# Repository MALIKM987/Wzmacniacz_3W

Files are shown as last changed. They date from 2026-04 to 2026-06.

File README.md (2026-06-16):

# Wzmacniacz audio 3 W z wejściem S/PDIF i DAC







## Spis treści

1. [Opis projektu](#opis-projektu)
2. [Najważniejsze parametry](#najważniejsze-parametry)
3. [Architektura systemu](#architektura-systemu)
4. [Główne bloki funkcjonalne](#główne-bloki-funkcjonalne)
5. [Wyniki symulacji](#wyniki-symulacji)
6. [PCB i pliki projektowe](#pcb-i-pliki-projektowe)
7. [Struktura dokumentacji](#struktura-dokumentacji)
8. [Co pokazuje ten projekt](#co-pokazuje-ten-projekt)
9. [Status projektu](#status-projektu)

## Opis projektu

Repozytorium dokumentuje projekt **wzmacniacza audio z wejściem cyfrowym S/PDIF, przetwornikiem DAC AD1955 oraz tranzystorową końcówką mocy**. Projekt obejmuje tor cyfrowy, tor analogowy, stopień mocy, zasilanie, symulacje LTspice oraz projekt PCB wykonany w Altium Designer.

Założeniem było stworzenie układu, który odbiera sygnał cyfrowy audio przez wejście koaksjalne S/PDIF, konwertuje go do formatu I2S, przetwarza w DAC na sygnał analogowy, a następnie wzmacnia w tranzystorowej końcówce mocy.

Projekt jest dobrym przykładem połączenia elektroniki analogowej, cyfrowej, audio, symulacji oraz projektowania PCB.

## Najważniejsze parametry

| Parametr | Wartość / założenie |
|---|---|
| Typ urządzenia | wzmacniacz audio z wejściem cyfrowym |
| Wejście audio | koaksjalne S/PDIF |
| Konwersja S/PDIF -> I2S | DIR9001 |
| DAC | AD1955 |
| Konwersja I/V | wzmacniacze operacyjne AD797 |
| Sterowanie | mikrokontroler STM32F103, SPI |
| Stopień mocy | tranzystorowy, klasa A, topologia inspirowana Linsley-Hood 1969 |
| Tranzystory mocy | MJL4281AG |
| Tranzystory driverów | BD139 |
| Tranzystory pomocnicze | BC557C |
| Założona moc wyjściowa | powyżej 3 W |
| Wynik symulacji mocy | ok. 12,9 W RMS dla obciążenia 8 ohm |
| Pasmo z symulacji | ok. 11,14 Hz - 5,18 MHz |
| Wzmocnienie napięciowe | ok. 16,25 V/V, czyli 24,22 dB przy 1 kHz |
| THD z symulacji | ok. 4,22E-03 |
| Sprawność z symulacji | ok. 25,32% |
| Zasilanie stopnia mocy | +36 V |
| Zasilanie analogowe | symetryczne +/-12 V |
| Zasilanie pomocnicze | +/-5 V oraz +3,3 V |
| Projekt PCB | Altium Designer |
| Symulacje | LTspice |

## Architektura systemu

```mermaid
flowchart LR
    A[Wejscie S/PDIF RCA] --> B[DIR9001 konwerter S/PDIF do I2S]
    B --> C[Bufor SN74LVU04A]
    C --> D[DAC AD1955]
    D --> E[Konwersja I/V i filtracja AD797]
    E --> F[Tranzystorowy wzmacniacz mocy klasa A]
    F --> G[Wyjscie glosnikowe]

    H[STM32F103] -->|SPI| D
    H -->|mute / volume| D

    I[Zasilanie] --> B
    I --> D
    I --> E
    I --> F
    I --> H
```

## Główne bloki funkcjonalne

| Blok | Opis | Dokumentacja |
|---|---|---|
| Konwerter S/PDIF -> I2S | odbiór cyfrowego sygnału audio i konwersja do I2S | [docs/03_tor_cyfrowy_spdif_i2s.md](docs/03_tor_cyfrowy_spdif_i2s.md) |
| DAC i tor analogowy | AD1955, konwersja I/V, filtracja i buforowanie | [docs/04_dac_tor_analogowy.md](docs/04_dac_tor_analogowy.md) |
| Mikrokontroler | sterowanie DAC przez SPI, mute, regulacja głośności | [docs/07_mcu_sterowanie.md](docs/07_mcu_sterowanie.md) |
| Wzmacniacz mocy | tranzystorowa końcówka mocy w klasie A | [docs/05_wzmacniacz_mocy.md](docs/05_wzmacniacz_mocy.md) |
| Zasilanie | +36 V, +/-12 V, +/-5 V, +3,3 V | [docs/06_zasilanie.md](docs/06_zasilanie.md) |
| PCB | projekt w Altium, rozmieszczenie bloków, Gerbery | [docs/09_pcb_altium.md](docs/09_pcb_altium.md) |
| Symulacje | LTspice, pasmo, wzmocnienie, moc, THD, sprawność | [docs/08_symulacje_ltspice.md](docs/08_symulacje_ltspice.md) |

## Wyniki symulacji

| Badanie | Wynik |
|---|---|
| Pasmo przenoszenia | ok. 11,14 Hz - 5,18 MHz |
| Wzmocnienie napięciowe | ok. 16,25 V/V |
| Wzmocnienie w dB | ok. 24,22 dB |
| Moc RMS | ok. 12,9 W |
| THD | ok. 4,22E-03 |
| Sprawność | ok. 25,32% |

Szczegóły znajdują się w pliku [docs/08_symulacje_ltspice.md](docs/08_symulacje_ltspice.md).

## PCB i pliki projektowe

Projekt PCB wykonano w **Altium Designer**. W repozytorium znajdują się pliki projektu, pliki wyjściowe oraz Gerbery.

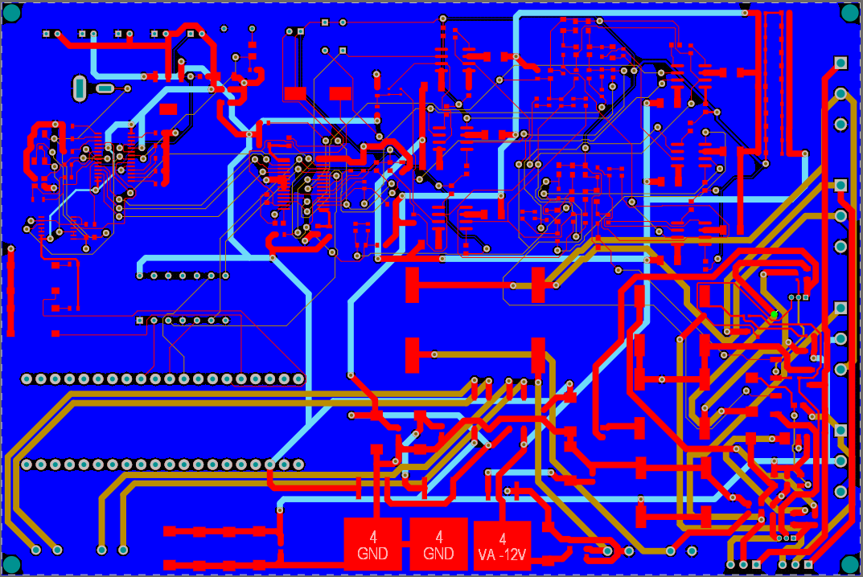
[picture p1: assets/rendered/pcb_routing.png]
Podgląd PCB ze sprawozdania


Najważniejsze katalogi źródłowe:

| Katalog | Zawartość |
|---|---|
| `pcb/` | projekt PCB Altium Designer |
| `pcb/Gerber/` | pliki produkcyjne Gerber |
| `sym/` | symulacje LTspice |
| `sprawozdanie/` | sprawozdanie projektowe |
| `prezentacja/` | prezentacja projektu |
| `literatura/` | noty katalogowe komponentów |

## Struktura dokumentacji

| Plik | Zawartość |
|---|---|
| [docs/00_spis_tresci.md](docs/00_spis_tresci.md) | pełny spis dokumentacji |
| [docs/01_architektura.md](docs/01_architektura.md) | architektura systemu |
| [docs/02_parametry_projektu.md](docs/02_parametry_projektu.md) | parametry i założenia |
| [docs/03_tor_cyfrowy_spdif_i2s.md](docs/03_tor_cyfrowy_spdif_i2s.md) | DIR9001, S/PDIF, I2S |
| [docs/04_dac_tor_analogowy.md](docs/04_dac_tor_analogowy.md) | AD1955 i tor analogowy |
| [docs/05_wzmacniacz_mocy.md](docs/05_wzmacniacz_mocy.md) | końcówka mocy klasy A |
| [docs/06_zasilanie.md](docs/06_zasilanie.md) | moduł zasilania |
| [docs/07_mcu_sterowanie.md](docs/07_mcu_sterowanie.md) | sterowanie mikrokontrolerem |
| [docs/08_symulacje_ltspice.md](docs/08_symulacje_ltspice.md) | wyniki symulacji |
| [docs/09_pcb_altium.md](docs/09_pcb_altium.md) | projekt PCB |
| [docs/10_bom_komponenty.md](docs/10_bom_komponenty.md) | elementy i ich rola |
| [docs/11_testy_walidacja.md](docs/11_testy_walidacja.md) | testy i walidacja |
| [docs/12_portfolio.md](docs/12_portfolio.md) | opis projektu do CV |
| [docs/13_todo_przed_publikacja.md](docs/13_todo_przed_publikacja.md) | lista poprawek przed publikacją |

## Co pokazuje ten projekt

Projekt pokazuje praktyczne umiejętności z zakresu:

- projektowania torów audio,
- doboru elementów analogowych i cyfrowych,
- projektowania wzmacniaczy tranzystorowych,
- pracy z układami DAC i interfejsem I2S,
- sterowania układami audio przez SPI,
- symulacji w LTspice,
- projektowania PCB w Altium Designer,
- przygotowania dokumentacji technicznej,
- analizy wyników: pasmo, wzmocnienie, moc, THD i sprawność.

## Status projektu

Projekt zawiera dokumentację, symulacje LTspice, schematy, PCB i Gerbery. Przed traktowaniem go jako gotowy produkt sprzętowy należy jeszcze wykonać weryfikację prototypu, pomiary laboratoryjne, kontrolę termiczną końcówki mocy oraz końcową walidację PCB.

## Autor

**Maciej Molik**

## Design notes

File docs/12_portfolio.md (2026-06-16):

# Opis projektu do portfolio

## Krótki opis

Wzmacniacz audio z wejściem S/PDIF, konwersją do I2S, przetwornikiem DAC AD1955 oraz tranzystorową końcówką mocy klasy A. Projekt obejmuje dobór komponentów, symulacje LTspice, projekt PCB w Altium Designer, dokumentację techniczną i analizę parametrów.

## Opis do CV

Zaprojektowano wzmacniacz audio z cyfrowym wejściem S/PDIF, konwersją DIR9001 do I2S, przetwornikiem AD1955 oraz tranzystorową końcówką mocy opartą o MJL4281AG, BD139 i BC557C. Wykonano symulacje LTspice, projekt PCB w Altium Designer oraz dokumentację techniczną obejmującą tor cyfrowy, analogowy, zasilanie i końcówkę mocy.

## Umiejętności pokazane w projekcie

- projektowanie torów audio,
- dobór komponentów analogowych i cyfrowych,
- projektowanie końcówki mocy,
- praca z DAC i interfejsem I2S,
- sterowanie układami przez SPI,
- symulacje LTspice,
- projektowanie PCB w Altium Designer,
- analiza parametrów: pasmo, wzmocnienie, moc, THD, sprawność,
- przygotowanie dokumentacji inżynierskiej.

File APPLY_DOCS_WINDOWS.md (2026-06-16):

# Jak zastosować tę paczkę w repozytorium

## 1. Rozpakuj ZIP

Rozpakuj paczkę dokumentacji obok lokalnego repozytorium projektu.

## 2. Wejdź do repozytorium

```powershell
cd "SCIEZKA_DO_REPO"
```

## 3. Utwórz branch

```powershell
git checkout main
git pull
git checkout -b docs/full-polish-audio-amplifier-docs
```

## 4. Skopiuj pliki

Jeżeli paczka jest rozpakowana obok repozytorium:

```powershell
robocopy "..\wzmacniacz_3w_full_polish_docs" "." /E
```

Kod wyjścia `1` z `robocopy` zwykle oznacza, że pliki zostały poprawnie skopiowane.

## 5. Commit i push

```powershell
git status
git add README.md docs assets CHANGELOG.md .gitignore
git commit -m "Add full Polish amplifier documentation"
git push -u origin docs/full-polish-audio-amplifier-docs
```

## 6. Otwórz Pull Request

Na GitHubie otwórz PR do `main`.

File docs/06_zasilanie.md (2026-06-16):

# Moduł zasilania

## Cel modułu

Moduł zasilania dostarcza stabilne napięcia dla części cyfrowej, analogowej oraz końcówki mocy. W projekcie występuje kilka domen zasilania, ponieważ różne bloki wymagają różnych napięć i poziomów zakłóceń.

## Napięcia w projekcie

| Napięcie | Zastosowanie |
|---|---|
| +36 V | końcówka mocy |
| +/-12 V | wzmacniacze operacyjne w torze analogowym |
| +5 V | część cyfrowa i pomocnicza |
| -5 V | wybrane obwody analogowe |
| +3,3 V | układy cyfrowe wymagające niższego napięcia |

## Elementy modułu

| Element | Rola |
|---|---|
| MB6S | mostki prostownicze |
| Kondensatory elektrolityczne | filtracja napięcia po prostowaniu |
| L7805 | stabilizacja +5 V |
| L7905 | stabilizacja -5 V |
| REG1117-3.3 | stabilizacja +3,3 V |
| Dławiki ferrytowe | ograniczenie zakłóceń i separacja domen |

## Diagram zasilania

```mermaid
flowchart LR
    A[Wejscie zasilania] --> B[Prostowniki]
    B --> C[Filtracja kondensatorami]
    C --> D[+36 V koncowka mocy]
    C --> E[+/-12 V tor analogowy]
    C --> F[+/-5 V]
    F --> G[+3.3 V]
    G --> H[DIR9001 / logika / MCU]
```

## Uwagi projektowe

W torze audio zasilanie ma bezpośredni wpływ na szumy i stabilność pracy. Należy dbać o krótkie ścieżki prądowe, separację masy analogowej i cyfrowej oraz odpowiednią filtrację przy każdym układzie scalonym.

## Schemat ze sprawozdania

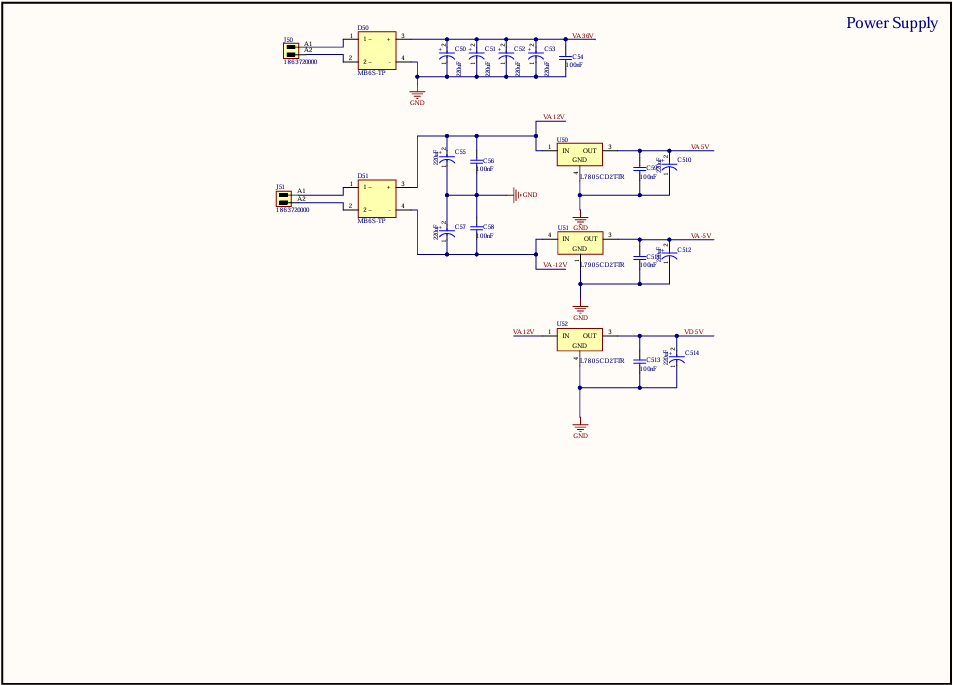
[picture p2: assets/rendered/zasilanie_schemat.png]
Schemat zasilania


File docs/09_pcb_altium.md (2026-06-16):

# Projekt PCB w Altium Designer

## Cel projektu PCB

Celem PCB było połączenie części cyfrowej, analogowej, zasilania i końcówki mocy w jednym projekcie. Płytka musi uwzględniać zarówno sygnały cyfrowe o wysokich zboczach, jak i niskoszumowy tor analogowy.

## Pliki projektowe

| Plik / katalog | Opis |
|---|---|
| `pcb/PCB_Project.PrjPcb` | projekt Altium |
| `pcb/Wzmacniacz audio.SchDoc` | schemat ideowy |
| `pcb/PCB_wzmacniacz_audio.PcbDoc` | projekt płytki |
| `pcb/Gerber/` | pliki produkcyjne |
| `pcb/Project Outputs for PCB_Project/` | wygenerowane pliki wyjściowe |
| `pcb/PCB_Project.pdf` | eksport projektu do PDF |

## Założenia PCB

- oddzielenie sekcji cyfrowej i analogowej,
- krótkie ścieżki dla sygnałów I2S,
- odpowiednio szerokie ścieżki zasilania i stopnia mocy,
- sensowne rozmieszczenie złączy,
- miejsce na elementy większej mocy i potencjalne radiatory,
- ograniczenie pętli masy,
- filtracja przy układach scalonych.

## Podgląd projektu

### Widok 3D PCB ze sprawozdania

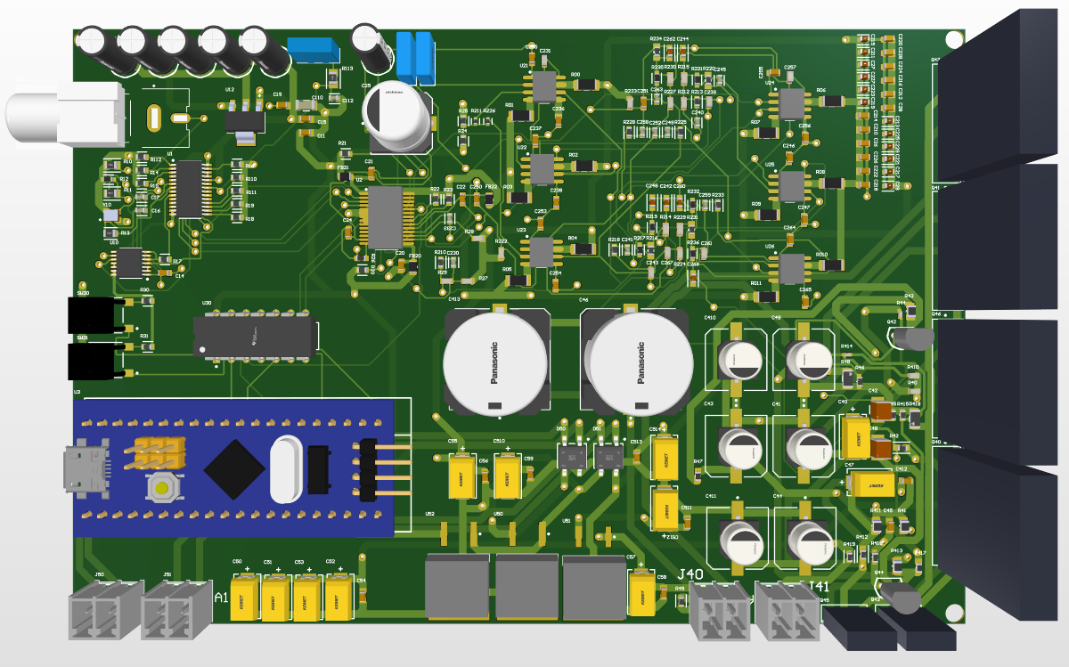
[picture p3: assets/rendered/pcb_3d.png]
Widok 3D PCB


### Routing PCB ze sprawozdania

PCB routing

### Szczegółowy widok PCB ze sprawozdania

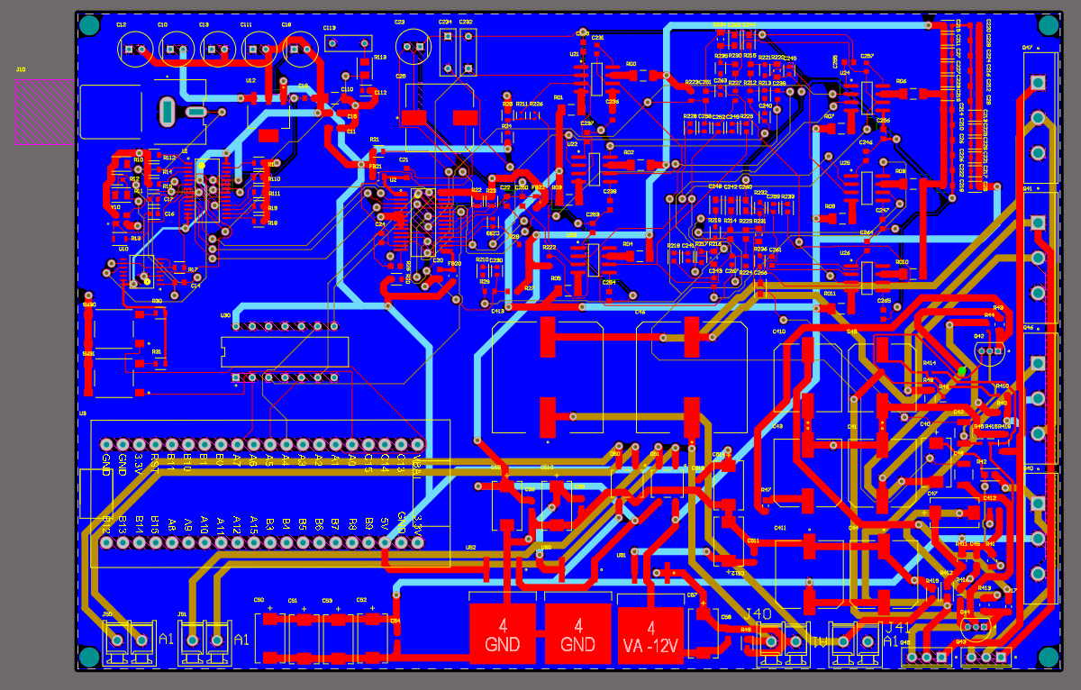
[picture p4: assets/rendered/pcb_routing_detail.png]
PCB routing detail


## Rzeczy do sprawdzenia przed produkcją

- DRC w Altium,
- szerokości ścieżek prądowych,
- odstępy izolacyjne,
- termika tranzystorów mocy,
- prowadzenie mas analogowych i cyfrowych,
- poprawność footprintów,
- polaryzacje kondensatorów i diod,
- zgodność Gerberów z projektem.

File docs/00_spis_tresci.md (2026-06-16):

# Spis treści dokumentacji

## Dokumenty główne

1. [Architektura systemu](01_architektura.md)
2. [Parametry projektu](02_parametry_projektu.md)
3. [Tor cyfrowy S/PDIF -> I2S](03_tor_cyfrowy_spdif_i2s.md)
4. [DAC i tor analogowy](04_dac_tor_analogowy.md)
5. [Wzmacniacz mocy](05_wzmacniacz_mocy.md)
6. [Zasilanie](06_zasilanie.md)
7. [Mikrokontroler i sterowanie](07_mcu_sterowanie.md)
8. [Symulacje LTspice](08_symulacje_ltspice.md)
9. [PCB w Altium Designer](09_pcb_altium.md)
10. [BOM i komponenty](10_bom_komponenty.md)
11. [Testy i walidacja](11_testy_walidacja.md)
12. [Opis do portfolio](12_portfolio.md)
13. [TODO przed publikacją](13_todo_przed_publikacja.md)

## Najważniejsze pliki źródłowe projektu

| Ścieżka | Znaczenie |
|---|---|
| `pcb/PCB_Project.PrjPcb` | projekt Altium Designer |
| `pcb/Wzmacniacz audio.SchDoc` | schemat ideowy |
| `pcb/PCB_wzmacniacz_audio.PcbDoc` | projekt PCB |
| `pcb/Gerber/` | pliki produkcyjne |
| `sym/amplifier.asc` | symulacja wzmacniacza mocy w LTspice |
| `sym/Power supply.asc` | symulacja zasilania w LTspice |
| `sprawozdanie/Sprawozdanie.pdf` | pełne sprawozdanie |
| `prezentacja/Prezentacja_WM.pdf` | prezentacja projektu |
| `literatura/` | noty katalogowe elementów |

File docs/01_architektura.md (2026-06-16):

# Architektura systemu

## Cel architektury

Projekt składa się z kilku bloków funkcjonalnych połączonych w jeden tor audio. Sygnał wejściowy jest cyfrowy, a sygnał wyjściowy jest analogowy i zasila głośnik.

## Diagram wysokiego poziomu

```mermaid
flowchart LR
    A[Wejscie koaksjalne S/PDIF] --> B[DIR9001]
    B --> C[I2S: LRCK, BCK, DATA]
    C --> D[SN74LVU04A]
    D --> E[AD1955 DAC]
    E --> F[Konwersja I/V AD797]
    F --> G[Filtracja analogowa]
    G --> H[Wzmacniacz mocy klasa A]
    H --> I[Glosnik]

    J[STM32F103] -->|SPI| E
    J -->|Mute i regulacja| E

    K[Zasilanie] --> B
    K --> E
    K --> F
    K --> H
    K --> J
```

## Przepływ sygnału audio

1. Sygnał cyfrowy S/PDIF trafia do gniazda RCA.
2. DIR9001 dekoduje S/PDIF i odzyskuje sygnały zegarowe oraz dane audio.
3. Sygnały I2S są buforowane i kształtowane przez SN74LVU04A.
4. AD1955 zamienia dane cyfrowe PCM na sygnał analogowy prądowy.
5. Wzmacniacze operacyjne AD797 realizują konwersję prąd-napięcie oraz filtrację.
6. Tranzystorowy stopień mocy wzmacnia sygnał do poziomu odpowiedniego dla głośnika.
7. Moduł zasilania dostarcza oddzielne napięcia dla części cyfrowej, analogowej i mocy.

## Podział na domeny

| Domena | Bloki |
|---|---|
| Cyfrowa | S/PDIF, DIR9001, SN74LVU04A, STM32F103, SPI |
| Konwersja C/A | AD1955 |
| Analogowa niskosygnałowa | konwersja I/V, AD797, filtracja |
| Moc | końcówka tranzystorowa, MJL4281AG, BD139, BC557C |
| Zasilanie | prostowniki, stabilizatory, kondensatory, separacja mas |

## Dlaczego taki podział jest ważny

W projekcie audio trzeba ograniczać przenikanie zakłóceń z części cyfrowej do analogowej. Dlatego istotny jest podział funkcjonalny, oddzielenie ścieżek zasilania, odpowiednie prowadzenie mas oraz logiczne rozmieszczenie bloków na PCB.

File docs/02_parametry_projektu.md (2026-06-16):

# Parametry projektu

## Założenia projektowe

| Parametr | Wartość |
|---|---|
| Moc wyjściowa | powyżej 3 W |
| Wejście | koaksjalne S/PDIF |
| Konwersja S/PDIF do I2S | DIR9001 |
| Przetwornik C/A | AD1955 |
| Sterowanie | mikrokontroler STM32F103, SPI |
| Stopień mocy | tranzystorowy, klasa A |
| Topologia końcówki | inspirowana Linsley-Hood 1969 |
| Zasilanie końcówki mocy | +36 V |
| Zasilanie analogowe | +/-12 V |
| Zasilanie pomocnicze | +/-5 V, +3,3 V |
| Narzędzia projektowe | Altium Designer, LTspice |

## Wyniki z symulacji

| Badany parametr | Wynik |
|---|---|
| Pasmo przenoszenia | ok. 11,14 Hz - 5,18 MHz |
| Wzmocnienie napięciowe | ok. 16,25 V/V |
| Wzmocnienie w dB | ok. 24,22 dB przy 1 kHz |
| Moc RMS | ok. 12,9 W |
| THD | ok. 4,22E-03 |
| Sprawność | ok. 25,32% |
| Obciążenie symulacyjne | 8 ohm |

## Uwaga o interpretacji wyników

Wyniki symulacji pokazują potencjalne parametry układu, ale nie zastępują pomiarów rzeczywistego prototypu. W przypadku końcówki mocy klasy A szczególnie ważne są pomiary temperatury, stabilności punktu pracy oraz rzeczywistego THD.

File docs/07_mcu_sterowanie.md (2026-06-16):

# Mikrokontroler i sterowanie

## Cel modułu

Mikrokontroler odpowiada za konfigurację przetwornika AD1955 i funkcje użytkowe, takie jak regulacja głośności, mute oraz potencjalna obsługa przycisków lub LED.

## Zakładany mikrokontroler

W dokumentacji projektu pojawia się mikrokontroler **STM32F103**. Jego główną rolą jest sterowanie układem DAC przez SPI.

## Funkcje sterowania

| Funkcja | Opis |
|---|---|
| Konfiguracja DAC | ustawienie formatu danych i trybu pracy AD1955 |
| Regulacja głośności | zapis wartości do rejestrów głośności DAC |
| Mute | wyciszenie sygnału audio |
| De-emfaza | opcjonalna konfiguracja trybu DAC |
| Interfejs użytkownika | potencjalne przyciski, enkoder lub LED |

## Diagram sterowania

```mermaid
flowchart LR
    A[Przyciski / UI] --> B[STM32F103]
    B -->|SPI: CCLK| C[AD1955]
    B -->|SPI: CLATCH| C
    B -->|SPI: CDATA| C
    B -->|MUTE| C
```

## Możliwa sekwencja startowa

1. Inicjalizacja zasilania i zegarów.
2. Reset lub ustawienie stanu początkowego DAC.
3. Konfiguracja formatu wejściowego.
4. Ustawienie poziomu głośności.
5. Wyłączenie mute po stabilizacji toru audio.

## Możliwe rozszerzenia

- enkoder do regulacji głośności,
- diody LED statusu,
- wybór źródła sygnału,
- zapamiętywanie ustawień,
- interfejs użytkownika z wyświetlaczem.

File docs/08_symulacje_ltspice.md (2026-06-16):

# Symulacje LTspice

## Cel symulacji

Symulacje służą do weryfikacji działania wzmacniacza mocy i zasilania przed wykonaniem lub uruchomieniem prototypu. W projekcie znajdują się pliki LTspice:

| Plik | Znaczenie |
|---|---|
| `sym/amplifier.asc` | symulacja końcówki mocy |
| `sym/Power supply.asc` | symulacja zasilania |

## Wyniki

| Badanie | Wynik |
|---|---|
| Pasmo przenoszenia | ok. 11,14 Hz - 5,18 MHz |
| Wzmocnienie napięciowe | ok. 16,25 V/V |
| Wzmocnienie w dB | ok. 24,22 dB |
| Moc RMS | ok. 12,9 W |
| THD | ok. 4,22E-03 |
| Sprawność | ok. 25,32% |

## Wzory używane w analizie

Wzmocnienie napięciowe:

$$
A_v = \frac{V_{out}}{V_{in}}
$$

Wzmocnienie w dB:

$$
A_{v,dB} = 20 \log_{10}(A_v)
$$

Moc na obciążeniu:

$$
P_{RMS} = \frac{V_{RMS}^2}{R}
$$

THD:

$$
THD = \frac{\sqrt{U_2^2 + U_3^2 + U_4^2 + ...}}{U_1}
$$

Sprawność:

$$
\eta = \frac{P_{out,RMS}}{I_{spocz} \cdot V_{CC}}
$$

## Zrzuty z symulacji

### Pasmo przenoszenia

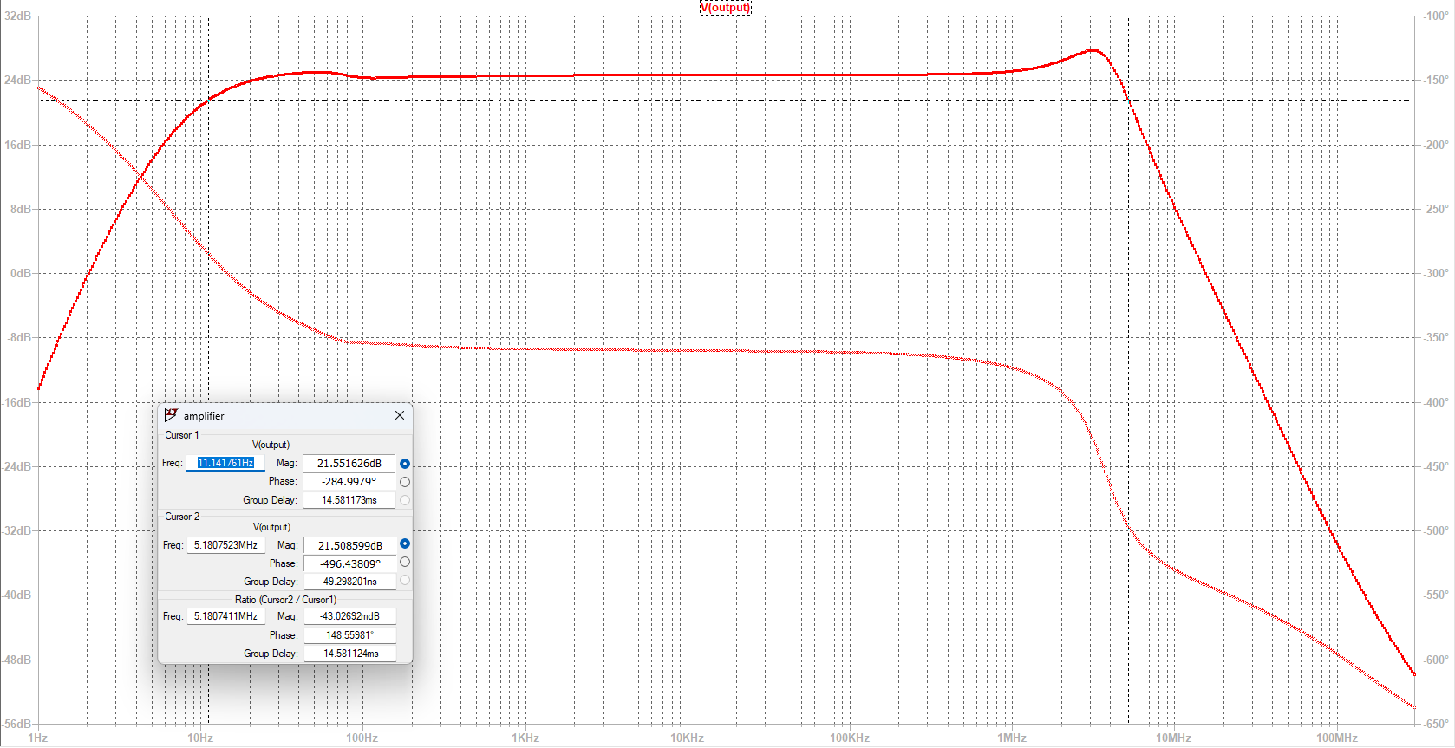
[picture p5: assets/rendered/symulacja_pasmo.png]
Pasmo przenoszenia


### Wzmocnienie

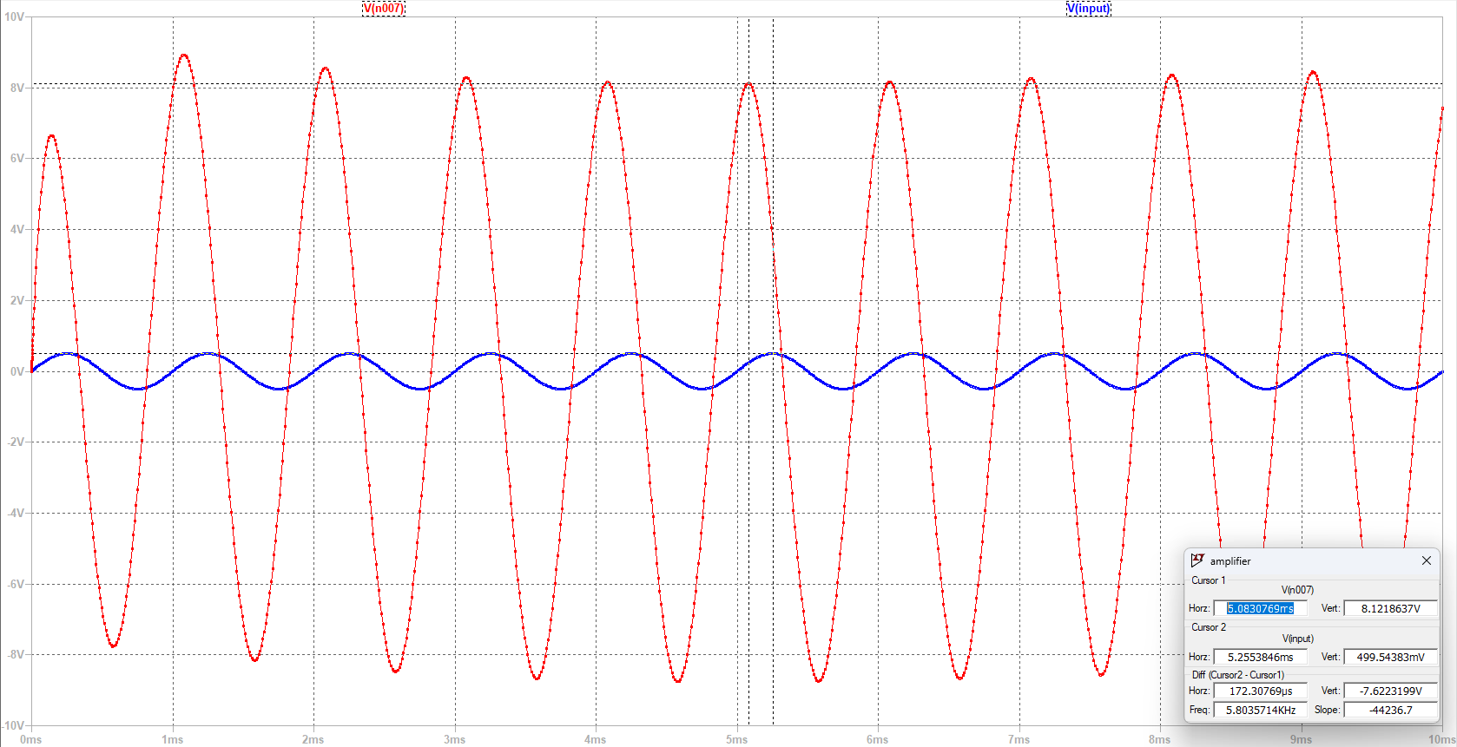
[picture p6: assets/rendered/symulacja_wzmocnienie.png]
Wzmocnienie


### Moc wyjściowa

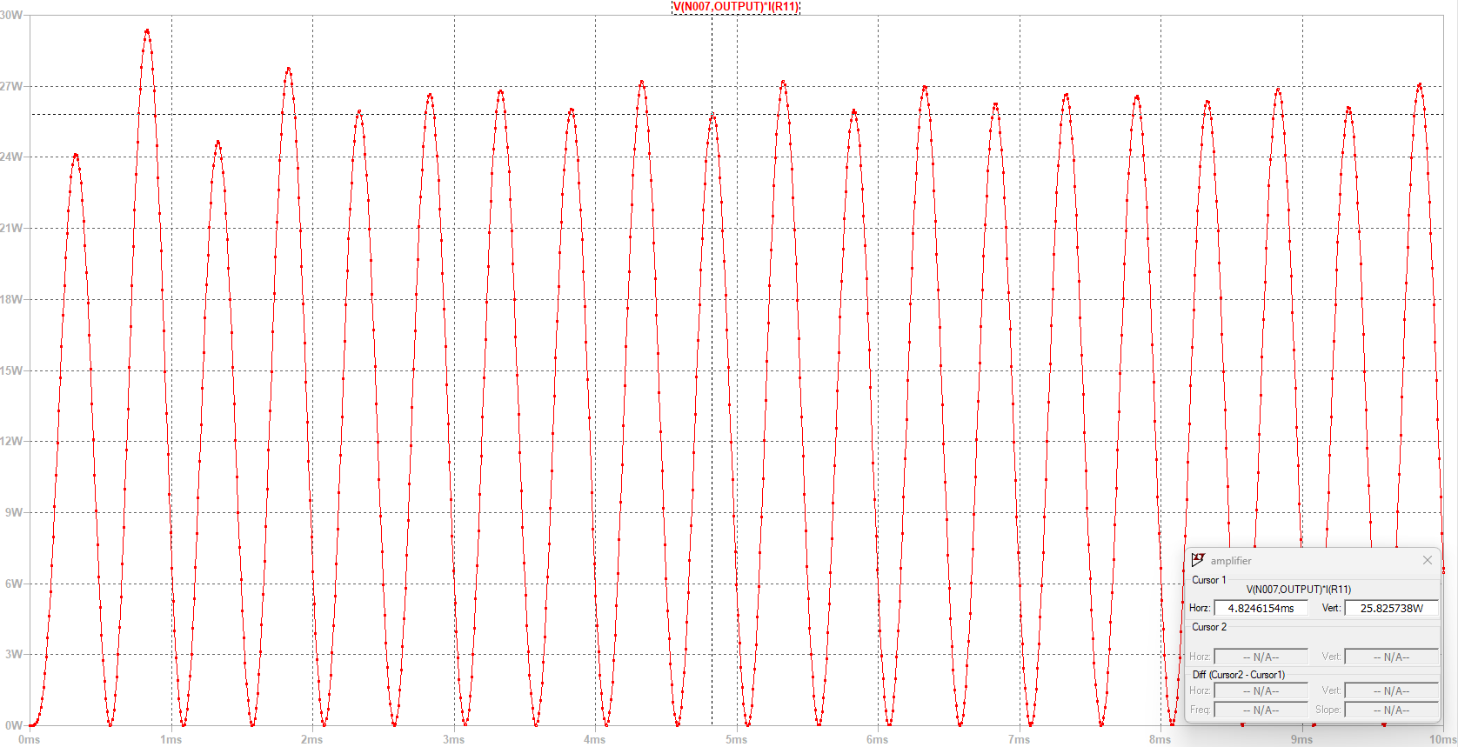
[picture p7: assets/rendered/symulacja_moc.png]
Moc wyjściowa


### THD

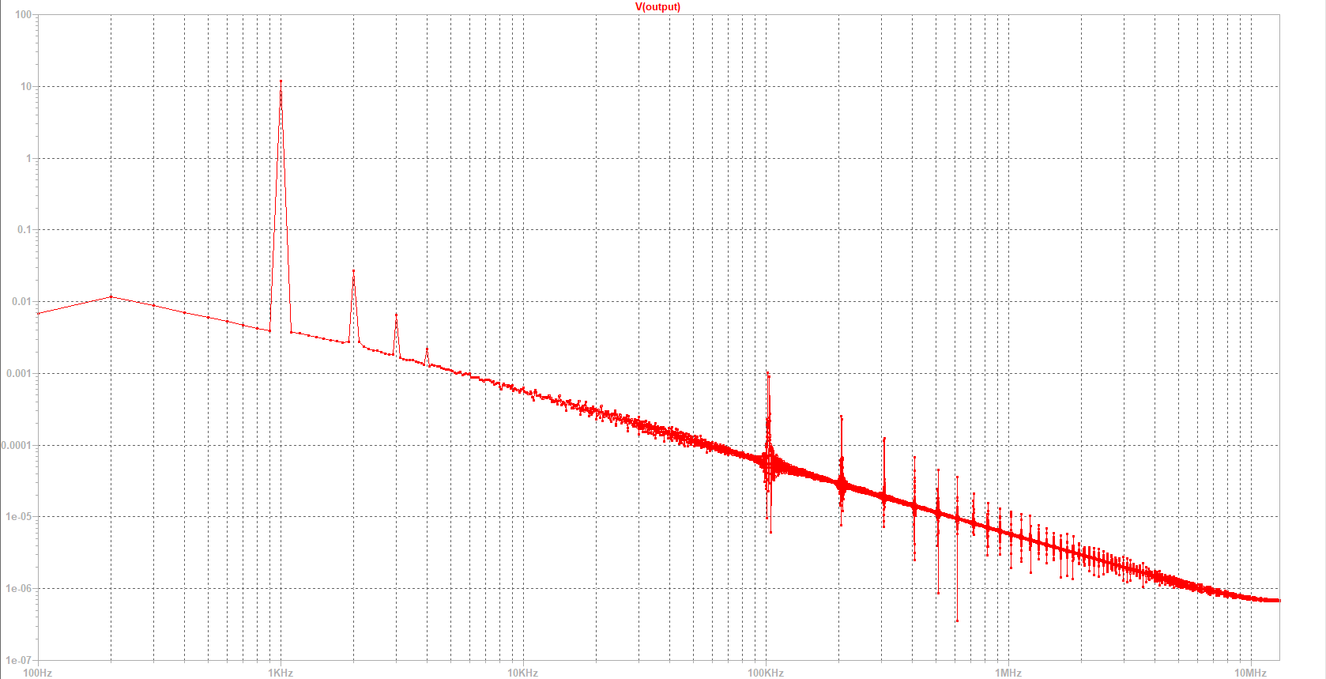
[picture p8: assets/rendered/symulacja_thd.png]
THD


### Sprawność

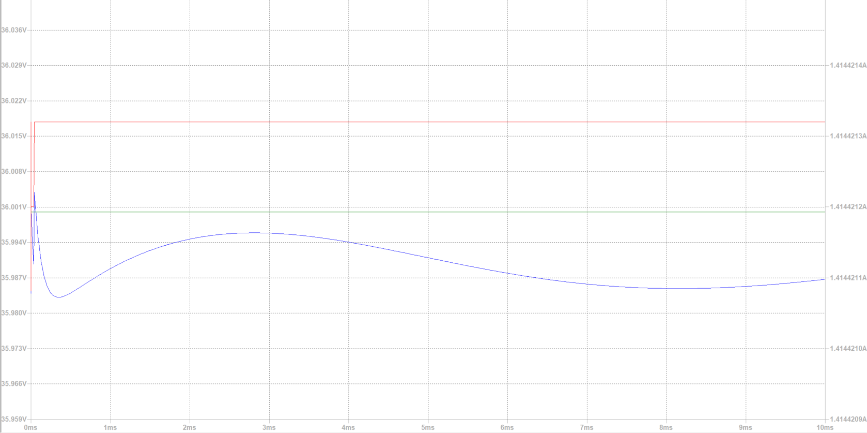
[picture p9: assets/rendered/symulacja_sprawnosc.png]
Sprawność


## Interpretacja

Symulacje wskazują, że projekt przekracza założenie mocy wyjściowej powyżej 3 W. Należy jednak pamiętać, że rzeczywisty układ wymaga pomiarów laboratoryjnych, szczególnie w zakresie temperatury, zniekształceń i stabilności punktu pracy.

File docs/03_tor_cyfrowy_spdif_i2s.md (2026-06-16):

# Tor cyfrowy S/PDIF -> I2S

## Cel modułu

Moduł cyfrowy odbiera sygnał audio w standardzie S/PDIF i przygotowuje go do dalszej konwersji w przetworniku AD1955. Kluczowym zadaniem jest odzyskanie danych PCM oraz sygnałów zegarowych.

## Elementy modułu

| Element | Rola |
|---|---|
| DIR9001 | odbiornik S/PDIF i konwerter do I2S |
| SN74LVU04A | buforowanie i kształtowanie sygnałów logicznych |
| RCJ-043 | gniazdo RCA dla wejścia koaksjalnego |
| Kwarc 24,576 MHz | źródło zegara dla odbiornika cyfrowego |

## Przepływ sygnału

```mermaid
flowchart LR
    A[Gniazdo RCA] --> B[Sygnał S/PDIF]
    B --> C[DIR9001]
    C --> D[LRCKO]
    C --> E[BCKO]
    C --> F[DOUT]
    D --> G[SN74LVU04A]
    E --> G
    F --> G
    G --> H[DAC AD1955]
```

## Rola DIR9001

DIR9001 dekoduje sygnał S/PDIF, odzyskuje zegar przez PLL i generuje sygnały zgodne z interfejsem audio I2S. Dzięki temu układ DAC może otrzymać dane PCM w formacie możliwym do konwersji na sygnał analogowy.

## Rola SN74LVU04A

SN74LVU04A pełni rolę bufora i układu poprawiającego zbocza sygnałów logicznych. Jest to ważne, ponieważ sygnały zegarowe I2S mają duży wpływ na jakość konwersji cyfrowo-analogowej.

## Schemat ze sprawozdania

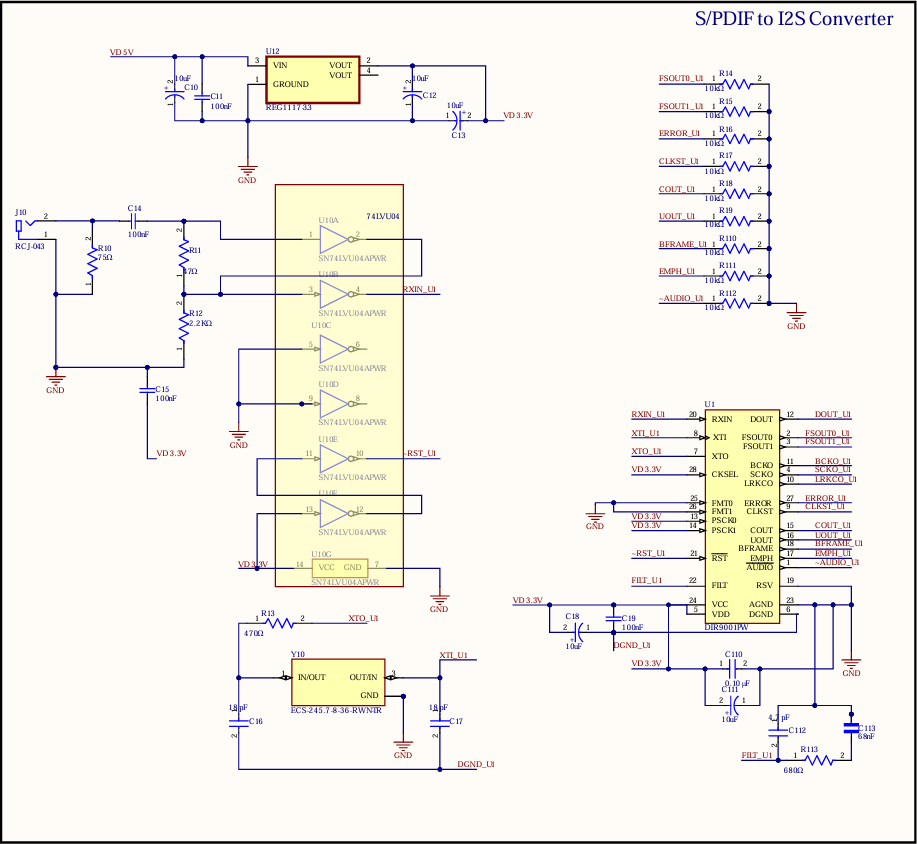
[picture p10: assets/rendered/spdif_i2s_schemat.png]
Schemat S/PDIF do I2S


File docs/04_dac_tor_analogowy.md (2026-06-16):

# DAC i tor analogowy

## Cel modułu

Moduł DAC zamienia cyfrowe dane audio w formacie I2S na analogowy sygnał audio. W projekcie zastosowano przetwornik AD1955, który jest układem audio wysokiej jakości.

## Elementy modułu

| Element | Rola |
|---|---|
| AD1955 | przetwornik cyfrowo-analogowy |
| AD797 | konwersja prąd-napięcie i filtracja |
| Elementy RC | filtracja i kształtowanie pasma |
| SPI z MCU | konfiguracja parametrów pracy DAC |

## Przepływ sygnału

```mermaid
flowchart LR
    A[I2S: LRCK, BCK, DATA] --> B[AD1955]
    B --> C[Wyjscia pradowe IOUT]
    C --> D[Konwersja I/V AD797]
    D --> E[Filtracja analogowa]
    E --> F[Wejscie wzmacniacza mocy]
```

## AD1955

AD1955 odbiera dane PCM, wykonuje cyfrową filtrację i konwersję sigma-delta, a następnie generuje analogowe sygnały prądowe. Układ może być konfigurowany przez SPI, co pozwala sterować formatem danych, głośnością i trybem mute.

## Konwersja I/V

Wyjścia DAC są prądowe, dlatego wymagają konwersji na napięcie. W projekcie wykorzystano wzmacniacze operacyjne AD797, które pełnią rolę konwerterów I/V oraz elementów filtracji analogowej.

## Znaczenie modułu

Ten blok ma duży wpływ na jakość całego wzmacniacza. Błędy w torze I/V, filtracji lub prowadzeniu masy mogą pogorszyć szumy, zniekształcenia i separację kanałów.

## Schemat ze sprawozdania

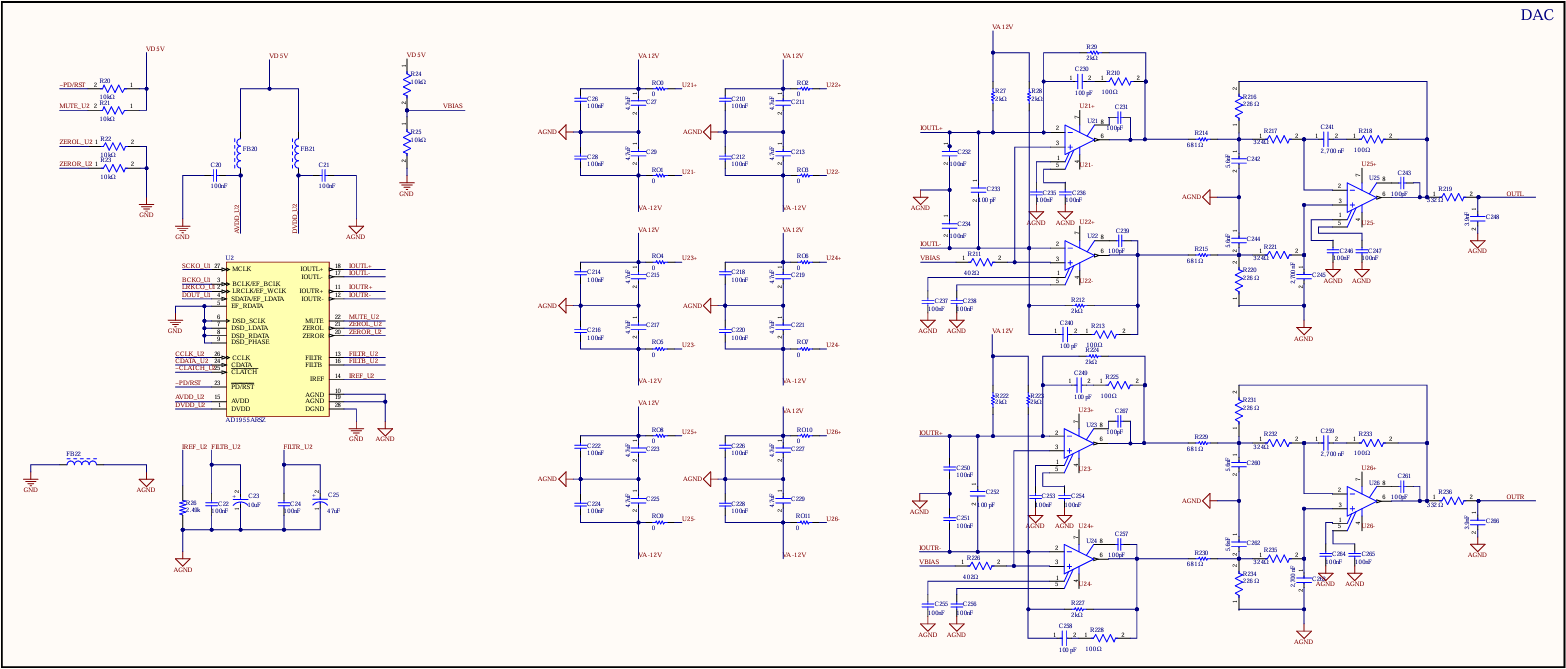
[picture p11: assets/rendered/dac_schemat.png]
Schemat DAC i toru analogowego


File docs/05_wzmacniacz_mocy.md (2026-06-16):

# Wzmacniacz mocy

## Cel modułu

Końcówka mocy wzmacnia sygnał analogowy do poziomu umożliwiającego zasilenie głośnika. W projekcie zastosowano tranzystorową końcówkę mocy pracującą w klasie A, inspirowaną topologią Linsley-Hood 1969.

## Elementy aktywne

| Element | Typ | Rola |
|---|---|---|
| MJL4281AG | tranzystor mocy NPN | główne elementy wykonawcze końcówki |
| BD139 | tranzystor NPN średniej mocy | sterowanie tranzystorami mocy |
| BC557C | tranzystor PNP małej mocy | polaryzacja i funkcje pomocnicze |

## Schemat blokowy końcówki mocy

```mermaid
flowchart LR
    A[Sygnał z DAC / I/V] --> B[Stopien sterujacy]
    B --> C[Driver BD139]
    C --> D[Tranzystory mocy MJL4281AG]
    D --> E[Wyjscie glosnikowe]
    F[Sprzezenie zwrotne] --> B
    E --> F
```

## Klasa A

W klasie A tranzystory przewodzą przez cały okres sygnału. Ogranicza to zniekształcenia przejścia, ale powoduje duże straty mocy i wymaga dobrego chłodzenia.

## Podstawowe zależności

Wzmocnienie napięciowe:

$$
A_v = \frac{V_{out}}{V_{in}}
$$

Wzmocnienie w decybelach:

$$
A_{v,dB} = 20 \log_{10}(A_v)
$$

Moc skuteczna na obciążeniu:

$$
P_{RMS} = \frac{V_{RMS}^2}{R}
$$

albo:

$$
P_{RMS} = I_{RMS}^2 \cdot R
$$

THD:

$$
THD = \frac{\sqrt{U_2^2 + U_3^2 + U_4^2 + ...}}{U_1}
$$

Sprawność:

$$
\eta = \frac{P_{out}}{P_{supply}}
$$

Dla uproszczonego przypadku:

$$
\eta = \frac{P_{out,RMS}}{I_{spocz} \cdot V_{CC}}
$$

## Uwagi praktyczne

Końcówka klasy A wymaga szczególnej uwagi przy projektowaniu termicznym. Tranzystory mocy powinny pracować z odpowiednim radiatorem, a punkt pracy powinien być zweryfikowany pomiarowo.

## Schemat ze sprawozdania

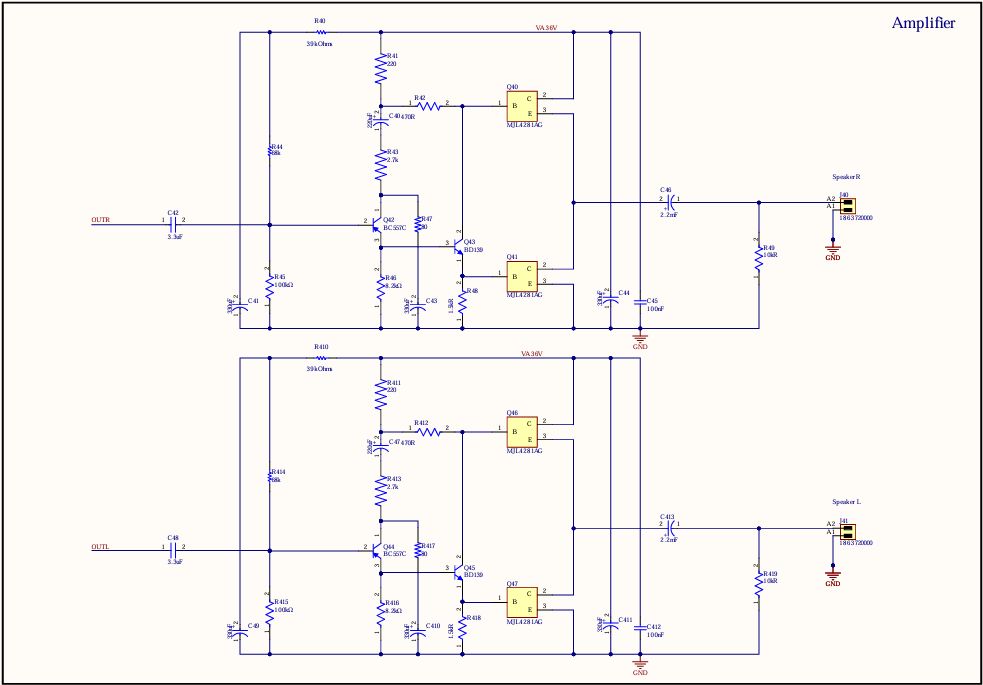
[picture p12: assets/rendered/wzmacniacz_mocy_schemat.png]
Schemat wzmacniacza mocy


## Schemat symulacyjny LTspice

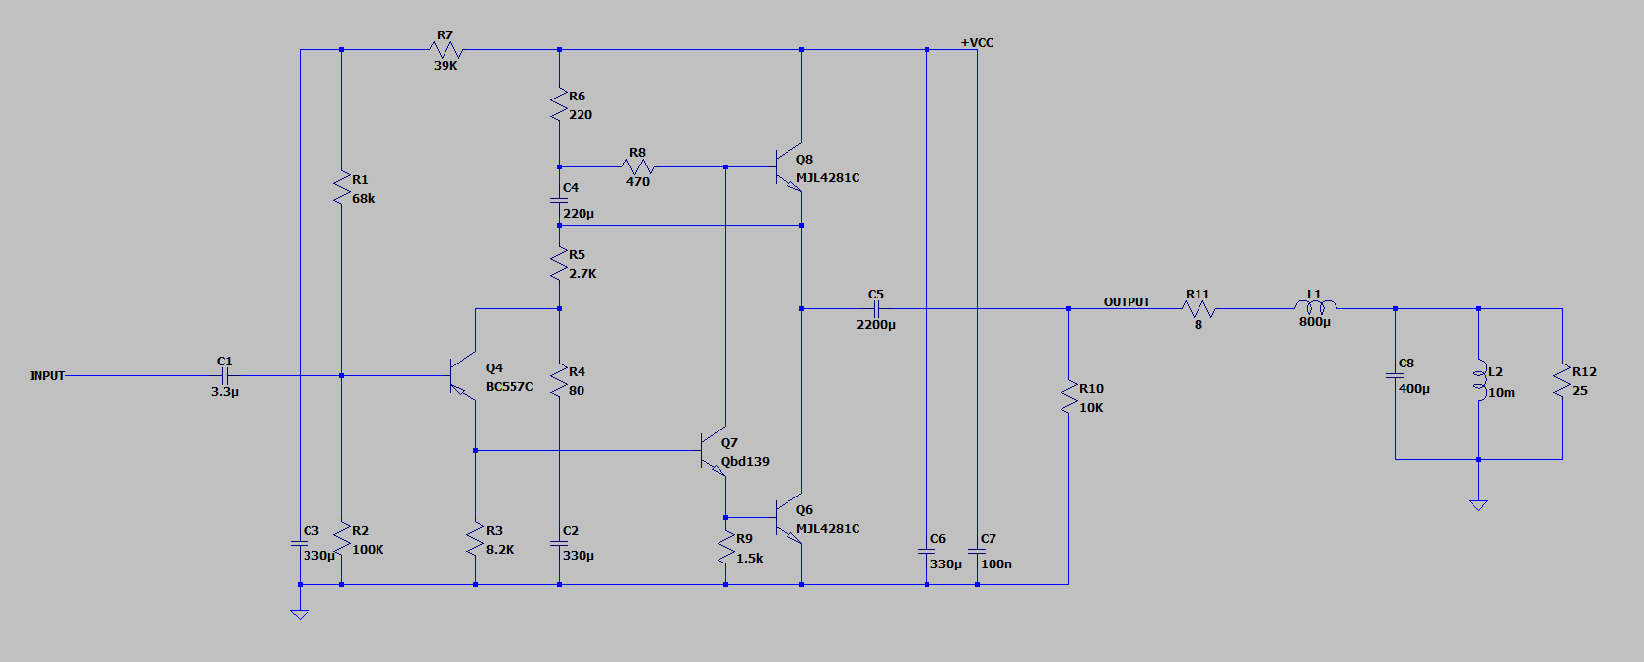
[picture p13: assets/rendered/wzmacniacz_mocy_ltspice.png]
Schemat LTspice wzmacniacza mocy


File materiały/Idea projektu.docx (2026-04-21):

Założenia:

Moc 3W

Wejście format S/PDIF

Kontrola głośności i wzmocnienia poszczególnych częstotliwości jest wykonana na mikrokontrolerze

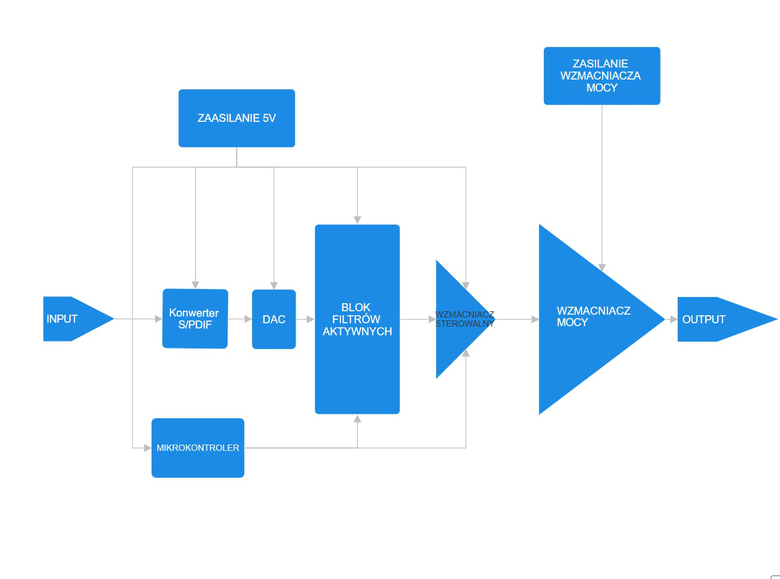
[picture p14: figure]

Lista propozycji elementów

Konwerter S/PDIF -> I2S

DIR9001

DAC

AD1852

AD1955

Wzmacniacz operacyjny do filtrów

AD8610 / AD8620

Wzmacniacz audio

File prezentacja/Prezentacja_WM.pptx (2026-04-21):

## Wzmacniacz audio z konwerterem S/PDIF i DAC

Autor: Maciej Molik
Elektronika
Przedmiot: Projektowanie Urządzeń Elektronicznych
Prowadzący: Cezary Worek
Data: 06.2025

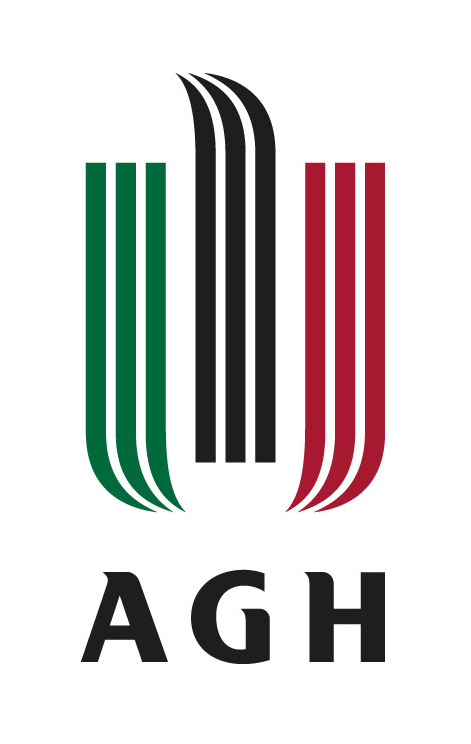
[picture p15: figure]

## Cel projektu

- Celem projektu jest zaprojektowanie i zbudowanie w pełni funkcjonalnego wzmacniacza audio zintegrowanego z wysokiej klasy przetwornikiem cyfrowo-analogowym (DAC). Układ odbiera sygnał cyfrowy S/PDIF, dekoduje do postaci PCM (I2S), konwertuje go w DAC do sygnału analogowego, a następnie wzmacnia sygnał analogowy zgodnie z parametrami ustalonymi przez mikrokontroler (głośność, mute).

## Założenia projektowe

- • Moc wyjściowa: >3 W • Wejście: S/PDIF koaksjalne • Sterowanie: mikrokontroler, SPI • Konwersja S/PDIF do I2S: DIR9001 • Przetwornik C/A: AD1955 • Końcówka mocy: tranzystorowa, klasa A • Symetryczne zasilanie ±12 V (sekcja analogowa) • Symetryczne ±5 V (cyfrowa) • Zasilanie 36 V dla stopnia mocy

## Schemat blokowy

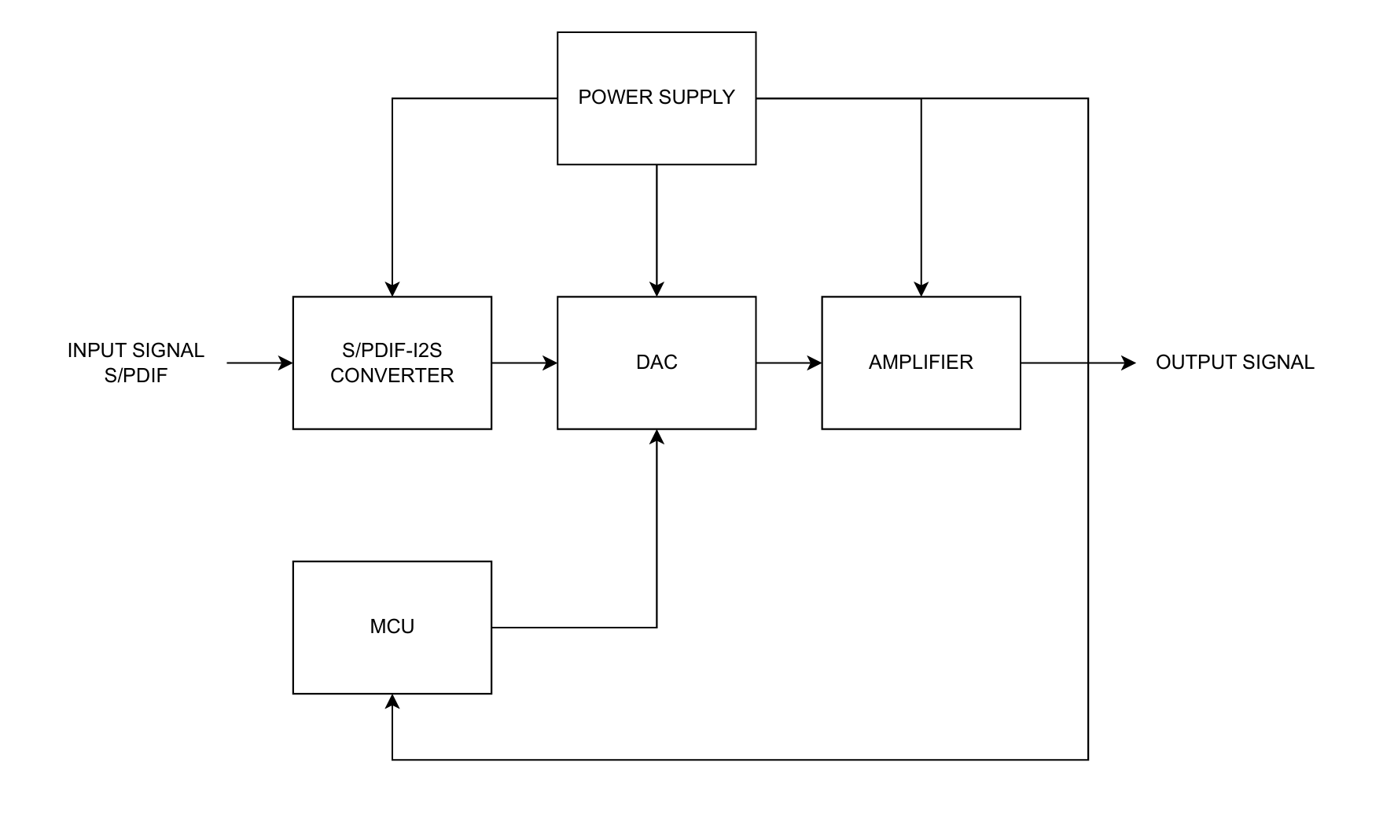
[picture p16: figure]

## Moduł konwertera S/PDIF → I2S

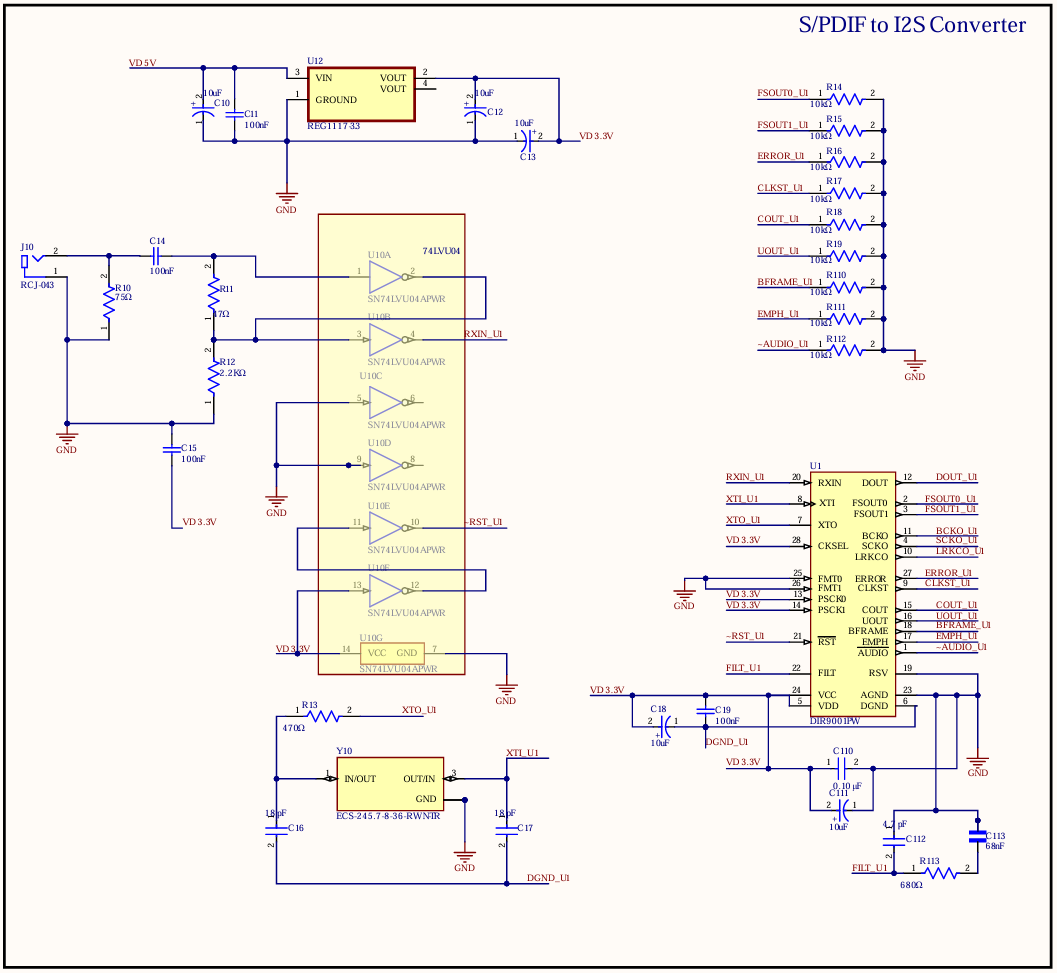
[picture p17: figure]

## Moduł konwertera S/PDIF → I2S

Moduł konwertera S/PDIF → I2S umożliwia odbiór cyfrowego sygnału audio (np. z odtwarzacza CD, TV) i przygotowanie go do konwersji na analogowy sygnał audio.
Wchodzący sygnał S/PDIF (kodowany w standardzie biphase mark code, BMC) podawany jest na gniazdo RCA (RCJ-043), a następnie trafia do odbiornika DIR9001.
DIR9001 dekoduje dane audio i odzyskuje sygnały zegarowe – przy użyciu wbudowanego PLL synchronizuje się z sygnałem wejściowym, minimalizując jitter. Na wyjściu DIR9001 generuje sygnały:
- LRCKO – sygnał ramki audio (Left/Right Clock),
- BCKO – zegar bitowy,
- DOUT – zdekodowane dane audio PCM (16/24-bit).
Dodatkowy bufor logiczny SN74LVU04A służy do kształtowania sygnałów I2S – eliminuje zniekształcenia, poprawia ostrość zboczy i zwiększa odporność na zakłócenia przy przesyłaniu danych.
Kwarc 24,576 MHz stanowi stabilne źródło zegara dla DIR9001, umożliwiając dokładne dekodowanie sygnału i utrzymanie wysokiej jakości transmisji.

## Moduł DAC – AD1955

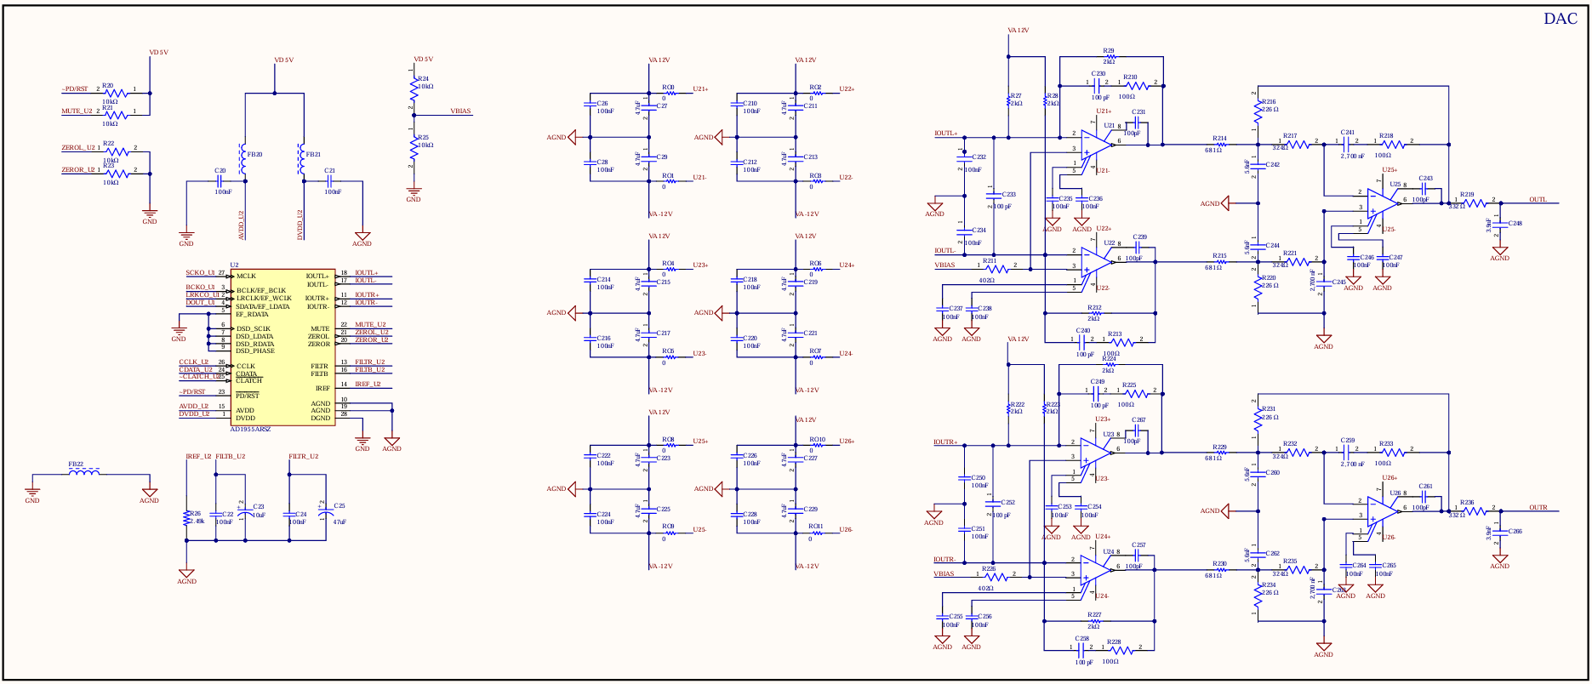
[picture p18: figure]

## Moduł DAC – AD1955

Moduł DAC (Digital-to-Analog Converter) to kluczowy element, który przekształca sygnał cyfrowy (I2S) na wysokiej jakości sygnał analogowy audio.
Sygnał cyfrowy w formacie I2S (LRCK, BCK, SDATA) jest dostarczany do wejść układu AD1955. Ten zaawansowany przetwornik audio wykorzystuje technologię sigma-delta oraz wbudowane filtry interpolacyjne, aby zminimalizować zniekształcenia i zapewnić wysoką jakość dźwięku.
Wyjścia prądowe AD1955 (IOUTL±, IOUTR±) są przekształcane na napięciowe za pomocą precyzyjnych układów konwersji prąd-napięcie (I/V) opartych na wzmacniaczach operacyjnych (np. AD797). Te układy pełnią również funkcję filtracji pasma i eliminacji aliasingu, co jest niezbędne w aplikacjach audio wysokiej jakości.
AD1955 umożliwia:
pracę z sygnałami PCM o częstotliwości próbkowania do 192 kHz,
rozdzielczość 16/18/20/24 bitów,
bardzo niski poziom szumów (SNR do 120 dB stereo) i zniekształceń (THD+N < –110 dB).
Sterowanie parametrami pracy (np. wybór formatu danych, częstotliwości próbkowania, trybu stereo/mono, de-emfazji czy poziomu głośności) odbywa się przez interfejs SPI (linie CCLK, CLATCH, CDATA). Mikrokontroler umożliwia łatwe i elastyczne dostosowanie pracy modułu do wymagań całego wzmacniacza.
Na wyjściu modułu DAC znajduje się sygnał analogowy audio, gotowy do wzmocnienia przez stopień mocy i zasilenia głośników.

## Moduł mikrokontrolera (MCU)

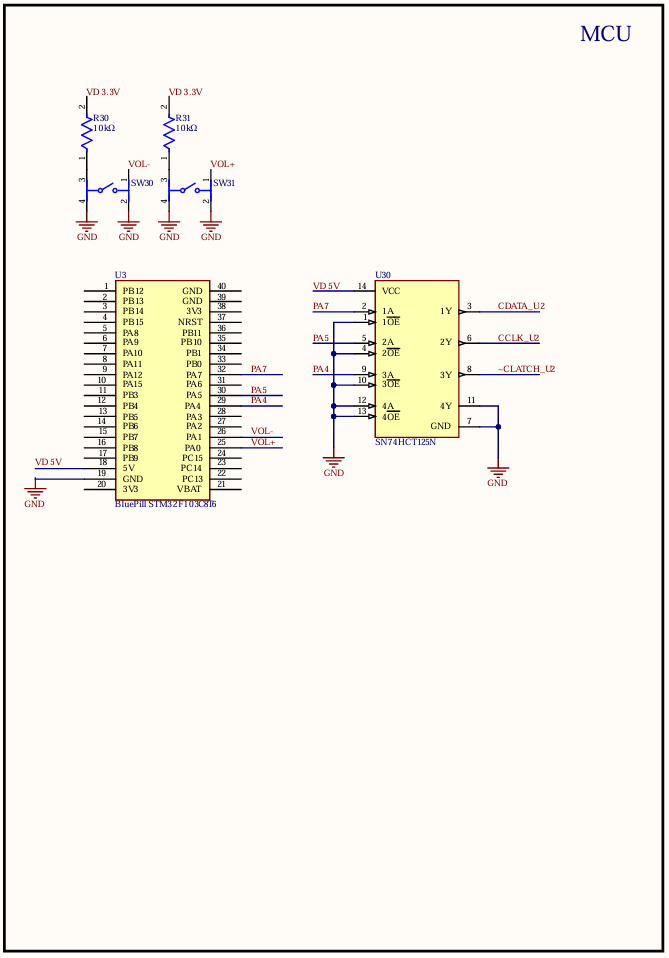
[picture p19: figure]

## Moduł mikrokontrolera (MCU)

Moduł MCU
- Sterowanie DAC AD1955 przez SPI (format, częstotliwość, głośność, mute).
- Cyfrowa regulacja głośności (14-bitowa).
- Sterowanie trybem mute i de-emfazą.
- Potencjalna obsługa przycisków/LED (interfejs użytkownika).
- Kluczowy element zapewniający elastyczność i zaawansowane funkcje wzmacniacza audio.

## Moduł wzmacniacza mocy

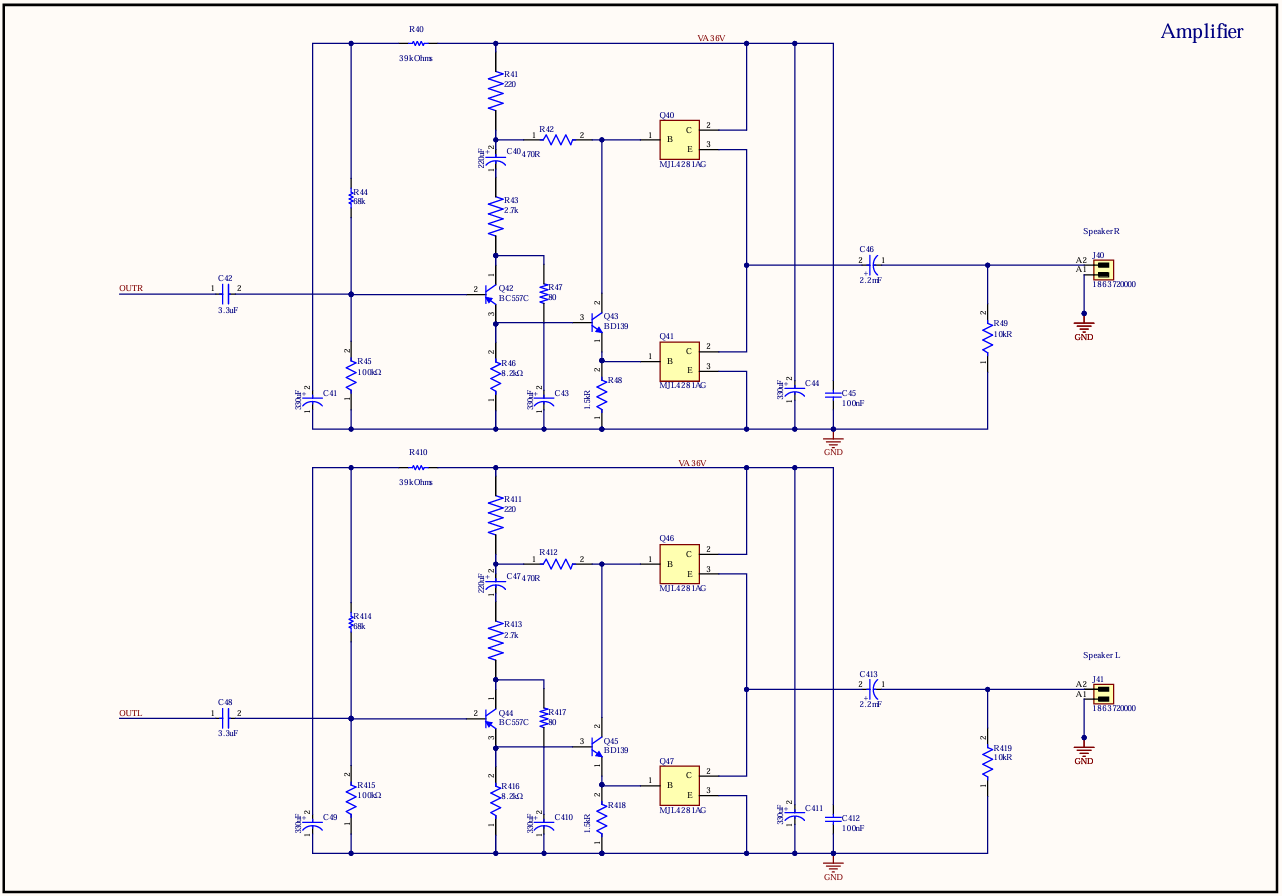
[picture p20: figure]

## Moduł wzmacniacza mocy

Moduł końcówki mocy wzmacnia sygnał analogowy do poziomu umożliwiającego zasilenie głośników. Wzmacniacz mocy został oparty o projekt Johna Lourencea Linsleya-Hooda z 1969.
Głównym elementem modułu są tranzystory mocy MJL4281AG, które oferują:
- maksymalny prąd kolektora: 15 A,
- napięcie kolektor-emiter: 350 V,
Ich zadaniem jest dostarczenie dużego prądu i napięcia do obciążenia (głośników), przy zachowaniu wysokiej liniowości sygnału i niskiego poziomu zniekształceń.
Driverami dla tych tranzystorów są BD139 – tranzystory średniej mocy, które wzmacniają napięciowo sygnał audio i dostarczają wymagany prąd bazy do tranzystorów mocy.
Parametry BD139:
- Ic = 1,5 A,
- Vce = 80 V,
pasmo przenoszenia: 190 MHz – szybka odpowiedź na sygnał.
Pomocnicze tranzystory BC557C (PNP) stabilizują pracę wzmacniacza – odpowiadają za precyzyjne ustawienie punktu pracy i kompensację termiczną.
Parametry BC557C:
- Ic = 100 mA,
- Vce = 50 V,
Końcówka mocy pracuje w klasie A, co oznacza, że przez tranzystory mocy płynie stały prąd spoczynkowy. Dzięki temu wyeliminowane są zniekształcenia przejściowe (crossover distortion), a dźwięk jest czysty i naturalny.
Zastosowane sprzężenie zwrotne stabilizuje wzmocnienie oraz minimalizuje zniekształcenia sygnału, co przekłada się na wysoką jakość brzmienia.
Końcówka mocy jest zasilana pojedynczym napięciem +36 V, co umożliwia osiągnięcie mocy wyjściowej > 3 W RMS dla głośników o impedancji 4–8 Ω.

## Moduł zasilania

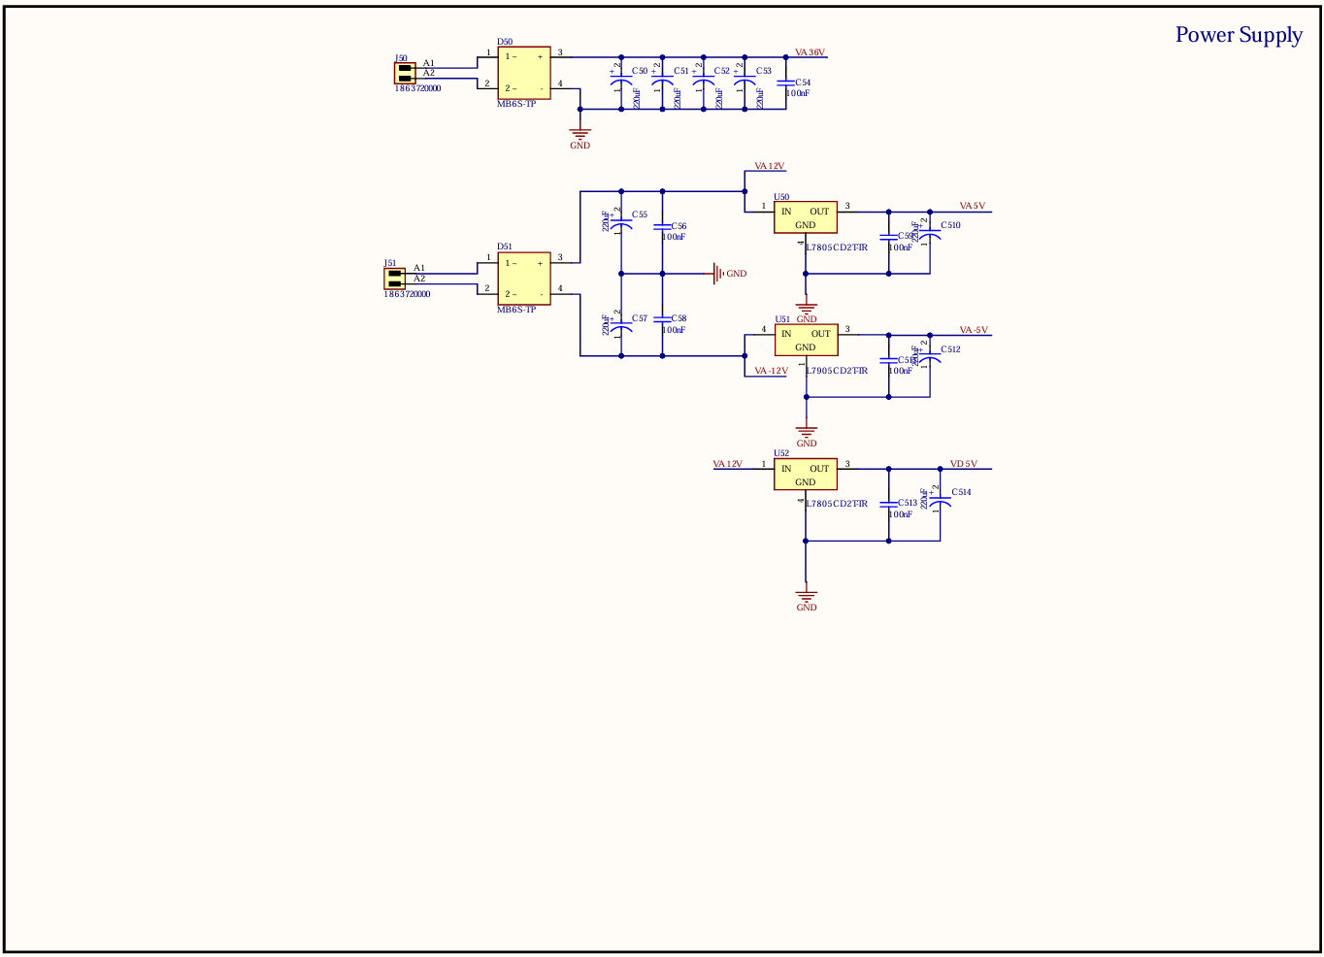
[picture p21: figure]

## Moduł zasilania

Moduł zasilania jest fundamentem stabilnej pracy całego wzmacniacza audio. Zapewnia:
- +3,3 V (cyfrowe układy: DAC, odbiornik S/PDIF),
- ±5 V (część analogowa),
- ±12 V (wzmacniacze operacyjne w filtrach I/V),
- +36 V (końcówka mocy).
Prostowniki MB6S i duże kondensatory filtrujące gwarantują stabilne, czyste napięcia.
Stabilizatory napięcia (L7805, L7905, REG1117-3.3) dbają o minimalne tętnienia i wysoką jakość zasilania.
Separacja mas i dławiki ferrytowe minimalizują zakłócenia między częściami cyfrowymi i analogowymi, co przekłada się na jakość dźwięku w systemie audio.

## Symulacja Wzmacniacza Mocy

Obraz zawierający diagram, linia, zrzut ekranu Zawartość wygenerowana przez AI może być niepoprawna.

## Symulacja Wzmacniacza Mocy

Symulacja wzmacniacza audio miała na celu sprawdzenie parametrów kluczowych dla jakości dźwięku: pasma przenoszenia, wzmocnienia, mocy wyjściowej i zniekształceń harmonicznych.
Wyniki potwierdziły szerokie pasmo przenoszenia (11 Hz – 5 MHz), wzmocnienie na poziomie 16–24 dB i możliwość oddania mocy szczytowej 25 W, co w praktyce przekłada się na około 13 W RMS przy obciążeniu 8 Ω.
Zniekształcenia THD wynoszą 0,42%, co plasuje wzmacniacz w klasie HiFi – zapewnia czysty, mocny dźwięk w całym paśmie słyszalnym.
Symulacja potwierdza, że układ jest zoptymalizowany pod kątem jakości audio i spełnia założenia projektowe.

## Badanie Pasma Przenoszenia

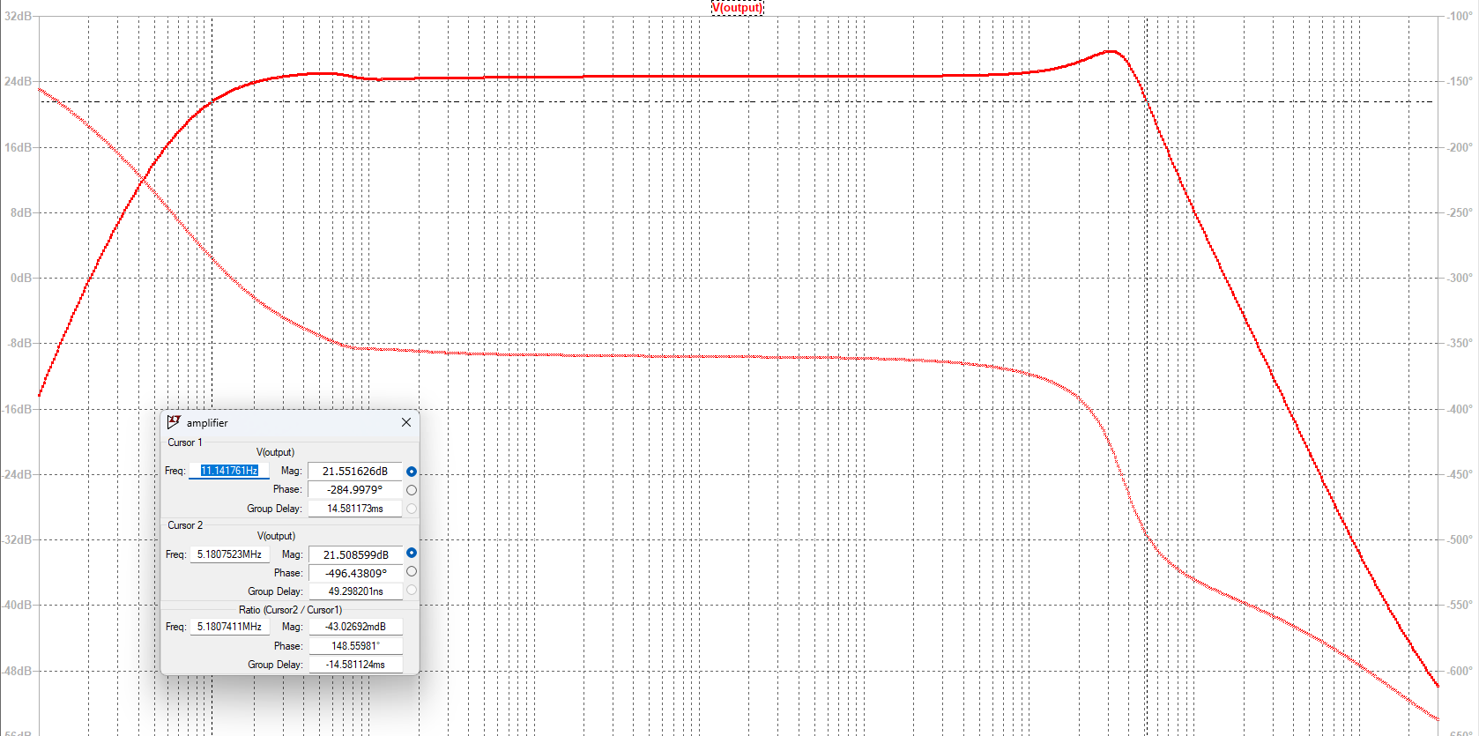
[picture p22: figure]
Obraz zawierający tekst, diagram, linia, Wykres Zawartość wygenerowana przez AI może być niepoprawna.

Symulacja układu wzmacniacza wykazała że pasmo tego układu wynosi od 11.14Hz do 5.18MHz

## Badanie Wzmocnienia Napięciowego

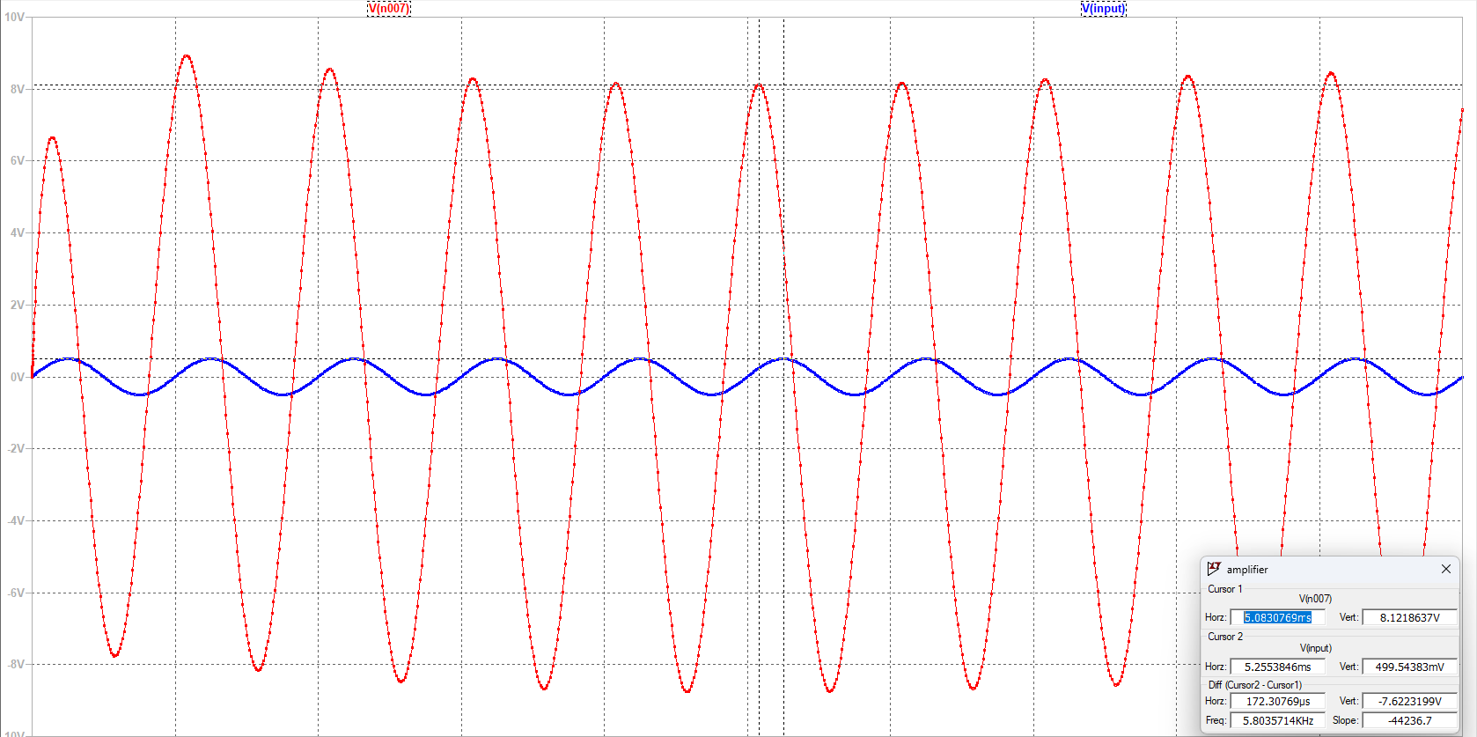
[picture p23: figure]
Obraz zawierający tekst, Wykres, zrzut ekranu, diagram Zawartość wygenerowana przez AI może być niepoprawna.

Symulacja układu wzmacniacza wykazała że wzmocnienie napięciowe obliczone ze wzoru
A_v =(A_(wy))/(A_(we))
I wynosi 16,25 V/V i 24,22 dB dla częstotliwości 1kHz

## Badanie Mocy Wyjściowej

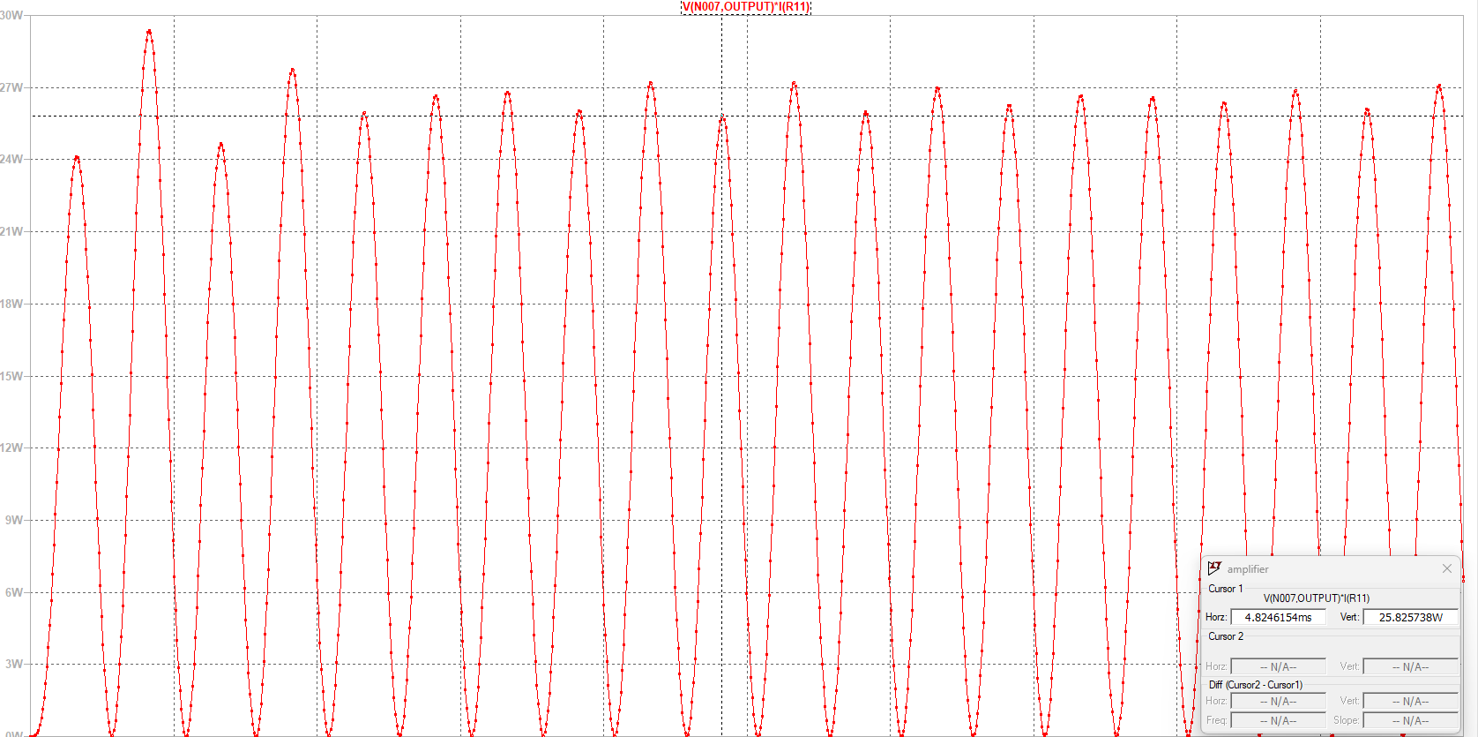
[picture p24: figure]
Obraz zawierający tekst, linia, diagram, Czcionka Zawartość wygenerowana przez AI może być niepoprawna.

Korzystając ze wzoru P_(rms) =(P_(max))/2
Otrzymujemy wynik 12,9W

## Badanie THD

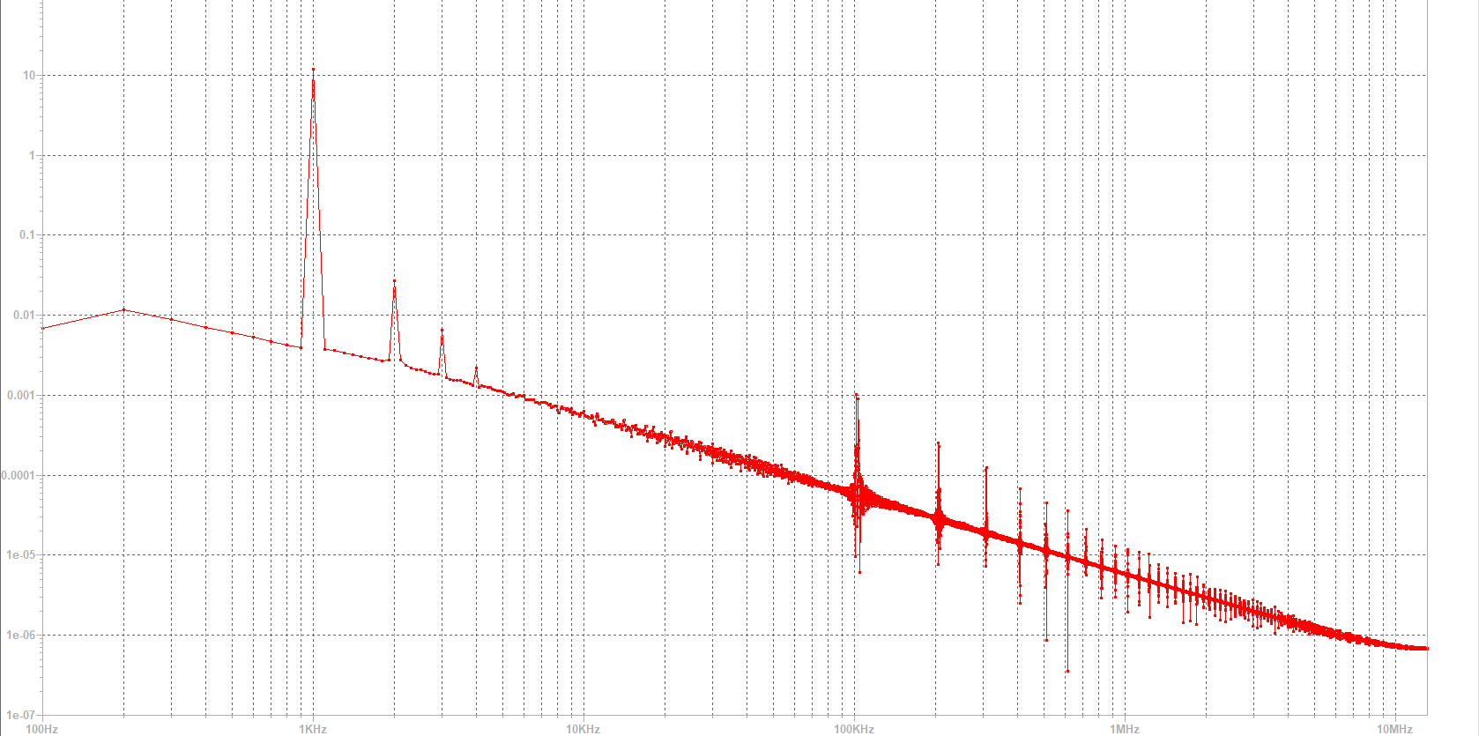
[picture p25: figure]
Obraz zawierający linia, tekst, Wykres, diagram Zawartość wygenerowana przez AI może być niepoprawna.

THD=(√(U_2^2 +U_3^2 +U_4^2))/(U_1)
Po obliczeniach otrzymaliśmy wynik że
THD = 4,22E-03

## Badanie Sprawnośći


Z symulacji wynika że sprawność według wzoru
η=(P_(out RMS))/(I_(spocz) ∙V_(cc))
wynosi 25,32%

## PCB

Obraz zawierający elektronika, obwód, Inżynieria elektroniczna, Komponent elektroniczny Zawartość wygenerowana przez AI może być niepoprawna.

## PCB

Najważniejsze cechy projektu PCB:
- Cztero-warstwowa płytka – stabilna praca i wysoka jakość sygnału
- Rozdzielenie mas analogowej i cyfrowej – minimalne zakłócenia
- Strefy masy i zasilania – lepsze ekranowanie i niskie szumy
- Przygotowanie do montażu SMD – kompaktowa, estetyczna płytka
- Miejsce na radiator – zapewnia stabilność termiczną tranzystorów mocy

Obraz zawierający tekst, mapa, zrzut ekranu, Prostokąt Zawartość wygenerowana przez AI może być niepoprawna.

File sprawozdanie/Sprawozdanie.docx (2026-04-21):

Obraz zawierający logo, Czcionka, tekst, symbol Zawartość wygenerowana przez sztuczną inteligencję może być niepoprawna.

| Wydział Informatyki, Elektroniki i Telekomunikacji, Katedra Elektroniki Studia inżynierskie I stopnia, stacjonarne Semestr 6-ty Elektroniki Przedmiot: Projektowanie Urządzeń

Tytuł: Wzmacniacz audio ze zintegrowanym przetwornikiem cyfrowo-analogowym

Autor: Maciej Molik

Prowadzący: Cezary Worek

Data: 06.2025

Cel projektu

Celem projektu jest zaprojektowanie i zbudowanie w pełni funkcjonalnego wzmacniacza audio, zintegrowanego z wysokiej klasy przetwornikiem cyfrowo-analogowym (DAC). Układ ma umożliwiać odbiór sygnału cyfrowego w standardzie S/PDIF, który następnie zostaje zdekodowany do postaci sygnału audio PCM (Pulse-Code Modulation).

Sygnał PCM w formacie I2S jest przesyłany do przetwornika cyfrowo-analogowego (DAC), który konwertuje dane cyfrowe na sygnał analogowy. Otrzymany sygnał analogowy jest następnie kształtowany i wzmacniany zgodnie z parametrami ustalonymi przez mikrokontroler ( głośność).

Końcowy sygnał analogowy trafia do stopnia mocy wzmacniacza, z którego wyprowadzany jest wzmocniony sygnał audio gotowy do zasilania głośników.

Projekt obejmuje również zaprojektowanie układu zasilania, który dostarcza odpowiednie napięcia do wszystkich komponentów wzmacniacza – zarówno części cyfrowej (S/PDIF, DAC), jak i analogowej (wzmacniacze operacyjne, stopień mocy).

Założenia projektowe

Projekt powinien spełniać następujące założenia projektowe

1. Moc wyjściowa: >3 W
2. Wejście: Wejście cyfrowe koaksjalne (S/PDIF)
3. Sterowanie: mikrokontroler z cyfrową regulacją głośności (możliwe rozszerzenie opcji)
4. Konwersja S/PDIF do I2S za pomocą DIR9001
5. Przetwornik C/A: AD1955
6. Stopień mocy: tranzystorowy, zasilany napięciem pojedynczym
7. Symetryczne zasilanie ±12 V – stosowane wyłącznie dla sekcji analogowej (op-ampy w prąd-napięcie DAC)
8. Symetryczne zasilanie ±5 V – stosowane wyłącznie dla sekcji
9. Zasilanie 36V – stosowane w końcówce mocy

Moduł konwertera S/PDIF → I2S

Cel modułu

Celem modułu konwertera S/PDIF → I2S jest umożliwienie odbioru sygnału cyfrowego audio w standardzie S/PDIF i konwersji go do formatu I2S, który jest standardowym interfejsem audio dla wysokiej jakości przetworników cyfrowo-analogowych (DAC). Moduł ten pełni kluczową rolę w torze audio – umożliwia dekodowanie sygnału cyfrowego oraz zapewnia sygnał zegarowy i dane audio w postaci kompatybilnej z dalszymi stopniami toru (DAC, wzmacniacz mocy).

Z czego się składa:

- DIR9001 (U1) – odbiornik sygnału S/PDIF
- SN74LVU04A (U10) – inwertery logiczne do kształtowania sygnałów
- RCJ-043 (J10) – gniazdo wejściowe RCA
- Kwarc 24,576 MHz (Y10) – stabilne źródło zegara

Obraz zawierający tekst, diagram, Plan, Równolegle Zawartość wygenerowana przez AI może być niepoprawna.

Zasada działania modułu

1. Wejście sygnału Sygnał cyfrowy S/PDIF (np. z odtwarzacza CD) podawany jest na wejście RCA (J10). Jest to sygnał kodowany w standardzie biphase mark code (BMC), zgodny z IEC60958/AES3.
2. Dekodowanie w DIR9001 Układ DIR9001 odbiera sygnał S/PDIF poprzez wejście RXIN, dekoduje dane audio oraz odzyskuje sygnały zegarowe.
  - Wykorzystuje PLL (Phase-Locked Loop) do synchronizacji z sygnałem wejściowym.
  - Oddziela dane audio (PCM) i generuje sygnały zegarowe:
    - LRCKO – sygnał ramki (Left/Right Clock)
    - BCKO – bit clock (zegar bitowy)
    - DOUT – zdekodowane dane audio w formacie I2S lub innym (wybieranym pinami FMT0, FMT1).
3. Rola SN74LVU04A (bufor logiczny) Chociaż wyjścia DIR9001 są logicznie kompatybilne, w praktycznych projektach audio przy wysokich częstotliwościach lub długich ścieżkach sygnałowych, mogą występować:
  - zniekształcenia zboczy sygnału,
  - obniżenie amplitudy sygnału logicznego,
  - zakłócenia EMI.

SN74LVU04A działa jako bufor i „odświeżacz” sygnału logicznego. Wzmacnia i kształtuje sygnały I2S, zapewniając:

  - ostrzejsze zbocza sygnału,
  - lepszą odporność na zakłócenia,
  - pełne dostosowanie poziomów logicznych do wymagań DAC (AD1955).
4. Przekazanie sygnału I2S Stabilny, wzmocniony sygnał I2S (LRCK, BCK, DATA) jest przesyłany dalej do przetwornika DAC AD1955, który zamienia go na sygnał analogowy.

Dlaczego wybrano takie elementy

- DIR9001
  - Bardzo niski jitter (50 ps rms), co jest kluczowe w aplikacjach audio wysokiej jakości.
  - Obsługa szerokiego zakresu częstotliwości próbkowania (28–108 kHz).
  - Łatwość integracji – pełne sterowanie sprzętowe lub możliwość współpracy z mikrokontrolerem.
  - Zgodność z I2S – umożliwia łatwe połączenie z DAC-iem AD1955.
- SN74LVU04A
  - Szybkie inwertery logiczne, które kształtują sygnał i eliminują zniekształcenia transmisyjne.
  - Pozwalają na uzyskanie maksymalnej jakości sygnału audio w krytycznych ścieżkach zegarowych i danych.
- Kwarc 24,576 MHz
  - Zapewnia stabilne i precyzyjne źródło zegara – wymagane dla poprawnej pracy DIR9001 (zgodnie z dokumentacją).

Podsumowanie

Moduł konwertera S/PDIF → I2S w projekcie wzmacniacza audio jest kluczowym ogniwem w torze sygnału. Oparty na układzie DIR9001, zapewnia niezawodne dekodowanie sygnału cyfrowego audio i jego konwersję do formatu I2S, wymaganego przez wysokiej klasy DAC AD1955. Zastosowanie dodatkowego bufora logicznego SN74LVU04A zapewnia maksymalną jakość i stabilność sygnałów logicznych. Dzięki temu możliwe jest uzyskanie dźwięku o wysokiej jakości, z minimalnym poziomem zakłóceń i jittera.

Moduł DAC (przetwornika cyfrowo-analogowego)

Cel modułu

Celem modułu DAC jest precyzyjna konwersja sygnału cyfrowego audio w standardzie I2S na sygnał analogowy napięciowy. Moduł ten odpowiada za jakość dźwięku w całym torze audio – jakość przetwarzania w DAC jest kluczowa dla późniejszego wzmocnienia w końcówce mocy.

Obraz zawierający tekst, diagram, Plan, wykres Zawartość wygenerowana przez AI może być niepoprawna.

Z czego się składa:
• AD1955 (U2) – wysokiej klasy 24-bitowy przetwornik cyfrowo-analogowy audio
• Wzmacniacze operacyjne AD797 – wysokiej jakości wzmacniacze w obwodach konwersji prąd-napięcie (I/V)

Zasada działania modułu

1. Odbiór sygnału I2S Sygnał cyfrowy audio w formacie I2S (LRCK – sygnał ramki, BCK – bit clock, SDATA – dane audio) trafia do wejść DAC AD1955.
2. Konwersja cyfrowo-analogowa AD1955 przetwarza dane audio PCM na sygnały analogowe prądowe (IOUTL± i IOUTR±) za pomocą wewnętrznego modulatora sigma-delta oraz interpolacyjnego filtra cyfrowego.
- Obsługuje częstotliwości próbkowania od 32 kHz do 192 kHz oraz słowo 16/18/20/24 bitów.
- Oferuje bardzo niski jitter, niski poziom zniekształceń (THD+N < –110 dB) oraz wysoki współczynnik SNR (120 dB stereo, 123 dB mono).
3. Konwersja prąd-napięcie (I/V) Wyjścia prądowe DAC są konwertowane na napięciowe w układach filtrów I/V opartych na wzmacniaczach AD797. Układy te pełnią jednocześnie funkcję filtracji (dzięki elementom RC), kształtując pasmo przenoszenia i minimalizując aliasing.
4. Buforowanie sygnału analogowego Wzmacniacze AD797 buforują sygnał napięciowy, zapewniając odpowiednią impedancję wyjściową i wysoką jakość sygnału przekazywanego do końcówki mocy.

Sterowanie parametrami pracy AD1955
AD1955 oferuje szerokie możliwości konfiguracji, sterowane przez interfejs SPI (piny CCLK, CLATCH, CDATA). Układ umożliwia m.in.:

- Wybór formatu i długości słowa danych PCM (I2S, Left-Justified, Right-Justified; 16/18/20/24 bity)
- Ustawienie częstotliwości próbkowania i trybu pracy interpolatora (48, 96, 192 kHz)
- Wybór trybu pracy: PCM, External Filter lub SACD (tryb slave/master)
- Konfigurację kanałów wyjściowych: stereo lub mono (lewy/prawy kanał)
- Aktywację de-emfazy dla próbkowania 32, 44,1 i 48 kHz
- Włączenie/wyłączenie funkcji mute (poprzez bit 14 rejestru 0 lub bezpośrednio pin MUTE)
- Regulację poziomu głośności niezależnie dla lewego i prawego kanału (rejestry 2 i 3, 14-bitowa regulacja)

Dzięki temu moduł DAC jest bardzo elastyczny i pozwala na dokładne dostosowanie parametrów pracy do wymagań systemu audio.

Dlaczego wybrano takie elementy
• AD1955 – DAC klasy high-end z wysokim SNR i bardzo niskim THD+N, idealny do aplikacji audio HiFi.
• AD797 – wzmacniacze o bardzo niskim poziomie szumów, szerokim paśmie przenoszenia i doskonałej liniowości, układ był też zalecany do użycia przez producenta.

Podsumowanie
Moduł DAC AD1955 w połączeniu z filtrami I/V opartymi na wzmacniaczach AD797 umożliwia precyzyjną konwersję sygnału cyfrowego na analogowy, gwarantując sygnał o bardzo wysokiej jakości i minimalnym poziomie zakłóceń. Możliwość sterowania rejestrami przez interfejs SPI pozwala na łatwe dostosowanie modułu do wymagań dowolnego systemu audio klasy HiFi.

Moduł mikrokontrolera (MCU)

Cel modułu
Celem modułu mikrokontrolera jest realizacja logiki sterowania całym wzmacniaczem audio. Mikrokontroler odpowiada za konfigurowanie parametrów pracy DAC-a AD1955 poprzez interfejs SPI, kontrolę poziomu głośności, obsługę trybu mute oraz ewentualnie dodatkowe funkcje użytkownika w ewentualnych następnych wersjach projektu (np. wybór źródła sygnału, obsługę przycisków). Dzięki temu moduł MCU jest kluczowym elementem w zapewnieniu elastycznego i wygodnego sterowania wzmacniaczem audio.

Z czego się składa:
• Mikrokontroler (np. STM32F103 lub inny, w zależności od projektu) – jednostka główna sterująca

Zasada działania modułu

1. Konfiguracja DAC AD1955 przez SPI Mikrokontroler wysyła do DAC-a słowa konfiguracyjne (16-bitowe) poprzez linie SPI (CCLK, CLATCH, CDATA), ustalając: • format i długość słowa PCM • częstotliwość próbkowania i tryb pracy • kanały wyjściowe (stereo/mono) • poziom głośności (ustawienie rejestrów regulacji) • aktywację/dezaktywację wyciszenia (mute) • de-emfazę i inne opcje
2. Sterowanie funkcją mute Mikrokontroler może sterować bezpośrednio linią MUTE w AD1955 (pin 22) lub ustawiać bit MUTE w rejestrze 0 przez SPI.
3. Obsługa regulacji głośności Mikrokontroler umożliwia płynne sterowanie poziomem głośności lewego i prawego kanału, zapisując odpowiednie wartości do rejestrów DAC-a (rejestry 2 i 3). Funkcja ta jest sprzętowo wspierana przez układ AD1955 (tzw. „clickless volume control”).
4. Ewentualne dodatkowe funkcje Mikrokontroler może obsługiwać dodatkowe elementy interfejsu użytkownika: • przyciski i enkodery do wyboru źródła, regulacji głośności • diody LED sygnalizujące stan pracy wzmacniacza • tryb „mute” lub „standby” całego układu

Dlaczego wybrano takie rozwiązanie
• Mikrokontroler umożliwia elastyczne sterowanie wszystkimi parametrami DAC-a AD1955, co jest nieosiągalne w prostych układach analogowych.

Podsumowanie
Moduł mikrokontrolera jest centralnym elementem logicznym wzmacniacza audio. Dzięki komunikacji z DAC-iem AD1955 przez interfejs SPI oraz obsłudze sygnałów sterujących, umożliwia pełną konfigurację toru audio – od wyboru formatu i częstotliwości próbkowania, przez regulację głośności, aż po aktywację wyciszenia. To rozwiązanie pozwala stworzyć elastyczny i zaawansowany wzmacniacz audio klasy HiFi

Moduł wzmacniacza mocy (stopień mocy)

Cel modułu
Celem modułu wzmacniacza mocy jest końcowe wzmocnienie sygnału analogowego z modułu DAC do poziomu umożliwiającego zasilenie głośników. Stopień mocy odpowiada za uzyskanie odpowiedniego prądu i napięcia wyjściowego, zapewniając jednocześnie wysoką jakość dźwięku, stabilność pracy i minimalne zniekształcenia sygnału audio.

Obraz zawierający tekst, diagram, Plan, linia Zawartość wygenerowana przez AI może być niepoprawna.

Z czego się składa:
• Tranzystory mocy MJL4281AG – tranzystory bipolarne dużej mocy, stanowiące główne elementy wzmacniające sygnał
• Tranzystory driverów BD139 – tranzystory średniej mocy odpowiedzialne za wysterowanie tranzystorów końcowych
• Tranzystory pomocnicze BC557C – małej mocy tranzystory pomocnicze w obwodach polaryzacji i zabezpieczeń

Zasada działania modułu

1. Klasa pracy Moduł wzmacniacza mocy pracuje w klasie A, co oznacza, że:
- Przez obydwa tranzystory mocy płynie cały czas duży prąd spoczynkowy (quiescent current).
- Oba tranzystory mocy zawsze przewodzą prąd, a ich rezystancje kolektor-emiter są modulowane przez sygnał audio.
- Dzięki temu sygnał wyjściowy jest wolny od zniekształceń przejściowych (crossover distortion) typowych dla klasy B lub AB.
2. Wzmocnienie i sterowanie
- Tranzystory driverów (BD139) wstępnie wzmacniają sygnał napięciowy z modułu DAC, umożliwiając skuteczne wysterowanie tranzystorów mocy (MJL4281AG).
- Tranzystory mocy wzmacniają sygnał do poziomu wymaganego do zasilenia głośników (moc wyjściowa do 3 W).
3. Ustalanie punktów pracy
- Wartość prądu spoczynkowego (Iidle) oraz napięcia na złączu kolektor-kolektor (½ napięcia zasilania) jest regulowana poprzez odpowiednio dobrane rezystory i potencjometry (np. R8 w klasycznym schemacie Linsley-Hooda).
- Duży prąd spoczynkowy płynie niezależnie od poziomu sygnału audio, co zapewnia brak zniekształceń przy małych sygnałach.
4. Sprzężenie zwrotne
- Wzmacniacz wykorzystuje sprzężenie zwrotne (rezystory R6 i R7 w klasycznym układzie), które stabilizuje prąd w obwodzie i wpływa na wzmocnienie napięciowe.
- Sprzężenie to pozwala zminimalizować różnice w pracy tranzystorów i stabilizować sygnał wyjściowy.

Dlaczego wybrano takie rozwiązanie
• Klasa A – zapewnia najwyższą jakość dźwięku dzięki pracy tranzystorów w pełnym zakresie sygnału bez zniekształceń crossover.
• Tranzystory mocy MJL4281AG – mają duży zapas mocy, wysoką liniowość i są dedykowane do audio HiFi.
• Tranzystory driverów i pomocnicze – dobrze znane, łatwo dostępne i idealne do aplikacji audio.
• Rozwiązanie Linsley-Hood – sprawdzona topologia wzmacniacza klasy A, z wysoką jakością brzmienia i bardzo niskim THD.

Podsumowanie
Moduł wzmacniacza mocy w stylu Linsley-Hood 1969 w Twoim projekcie zapewnia najwyższą jakość dźwięku dzięki pracy w klasie A oraz dobrze zaprojektowanemu sprzężeniu zwrotnemu. Tranzystory mocy MJL4281AG, sterowane przez tranzystory BD139 i wspomagane przez elementy pomocnicze BC557C, tworzą stabilny i liniowy tor sygnału. Dzięki temu możliwe jest wzmocnienie sygnału analogowego do poziomu 3 W RMS bez kompromisów jakościowych, co czyni ten projekt wzmacniacza audio idealnym dla entuzjastów HiFi.

Moduł zasilania

Cel modułu
Celem modułu zasilania jest dostarczenie odpowiednich napięć zasilających do wszystkich sekcji wzmacniacza audio, zapewniając im stabilne warunki pracy. Moduł ten odpowiada za konwersję napięcia zewnętrznego na napięcia potrzebne dla układów cyfrowych, analogowych oraz końcówki mocy, jednocześnie minimalizując zakłócenia i wpływ wahań napięcia zasilania na jakość sygnału audio.

Obraz zawierający tekst, diagram, zrzut ekranu, linia Zawartość wygenerowana przez AI może być niepoprawna.

Z czego się składa:
• Mostki prostownicze (MB6S) – odpowiadają za prostowanie napięcia AC dostarczanego do wzmacniacza.
• Duże kondensatory elektrolityczne (np. 2,2 mF, 330 µF, 220 µF) – wygładzają napięcie stałe po prostowaniu, redukując tętnienia.
• Stabilizatory napięcia (L7805, L7905, REG1117-3.3) – generują stabilne napięcia +5 V, –5 V oraz +3,3 V dla części cyfrowej i analogowej (np. DAC, odbiornik S/PDIF, mikrokontroler).

Zasada działania modułu

1. Prostowniki i filtracja Wejściowe napięcie AC jest prostowane przez mostki MB6S, tworząc napięcie stałe. Duże kondensatory elektrolityczne wygładzają to napięcie, redukując tętnienia i zakłócenia sieciowe, aby zapewnić stabilną podstawę zasilania dla wszystkich bloków wzmacniacza.
2. Stabilizacja napięć
- L7805 generuje napięcie +5 V dla części cyfrowej (np. odbiornik S/PDIF DIR9001, interfejsy mikrokontrolera).
- L7905 dostarcza napięcie –5 V, potrzebne dla wybranych obwodów analogowych.
- REG1117-3.3 stabilizuje napięcie +3,3 V dla układów cyfrowych pracujących w tym standardzie.
- Symetryczne napięcia ±12 V zasilają wzmacniacze operacyjne w torze analogowym (np. AD8610, AD8620, AD797).
3. Separacja masy i redukcja zakłóceń W projekcie zastosowano dławiki ferrytowe, które:
- Separują masę analogową od cyfrowej, ograniczając wpływ zakłóceń generowanych przez szybkie sygnały cyfrowe.
- W liniach zasilania DAC AD1955 minimalizują wpływ szumów i zakłóceń między sekcjami układu, poprawiając jakość dźwięku.
4. Zasilanie stopnia mocy Pojedyncze napięcie (np. +36 V) dostarcza energii do stopnia końcowego wzmacniacza mocy. Dzięki temu końcówka mocy ma wystarczającą rezerwę prądową, aby wysterować głośniki z odpowiednią mocą i dynamiką.

Dlaczego wybrano takie elementy
• Stabilizatory napięcia L7805, L7905 i REG1117-3.3 – popularne, sprawdzone rozwiązania gwarantujące niskie tętnienia i stabilne napięcia zasilania.
• Mostki prostownicze MB6S – kompaktowe, wydajne i łatwe w montażu, zapewniające niezawodne prostowanie napięcia.
• Duże kondensatory filtrujące – minimalizują zakłócenia w zasilaniu i wpływ tętnień na sygnał audio.
• Symetryczne zasilanie ±12 V – kluczowe dla uzyskania najlepszej jakości pracy wzmacniaczy operacyjnych w filtrach I/V.
• Pojedyncze napięcie +36 V – zapewnia odpowiedni zapas mocy dla stopnia końcowego wzmacniacza mocy.

Podsumowanie
Moduł zasilania w projekcie wzmacniacza audio dostarcza wszystkie niezbędne napięcia – od +3,3 V dla części cyfrowej, przez ±12 V dla precyzyjnych układów analogowych, aż po +36 V dla końcówki mocy. Stabilne, czyste napięcia zasilania są fundamentem dla uzyskania najwyższej jakości dźwięku w systemie audio klasy HiFi. Odpowiednia filtracja i stabilizacja pozwalają wyeliminować zakłócenia i wpływają na końcową jakość sygnału audio.

Symulacja projektu wzmacniacza audio

Układ symulowany

Obraz zawierający diagram, linia, zrzut ekranu Zawartość wygenerowana przez AI może być niepoprawna.

Cel symulacji
Celem symulacji jest weryfikacja poprawności działania całego układu wzmacniacza audio – w tym modułów: konwertera S/PDIF → I2S, DAC oraz końcówki mocy. Symulacja pozwala ocenić najważniejsze parametry końcówki mocy i całego toru analogowego, takie jak:

- wzmocnienie napięciowe,
- pasmo przenoszenia,
- moc wyjściowa,
- całkowite zniekształcenia harmoniczne (THD).

Wyniki symulacji układu obciążonego modelem głośnika 8 Ω

1. Badanie pasma przenoszenia

Symulacja układu wzmacniacza wykazała że pasmo tego układu wynosi od 11.14Hz do 5.18MHz

Obraz zawierający tekst, diagram, linia, Wykres Zawartość wygenerowana przez AI może być niepoprawna.

2. Badanie wzmocnienia napięciowego

Symulacja układu wzmacniacza wykazała że wzmocnienie napięciowe obliczone ze wzoru

A_v =(A_(wy))/(A_(we))

I wynosi 16,25 V/V i 24,22 dB dla częstotliwości 1kHz

Obraz zawierający tekst, Wykres, zrzut ekranu, diagram Zawartość wygenerowana przez AI może być niepoprawna.

3. Badanie mocy wyjściowej

Obraz zawierający tekst, linia, diagram, Czcionka Zawartość wygenerowana przez AI może być niepoprawna.

Symulacja wykazała że Pmax wynosi około 25.8W tzn korzystając z dwóch wzorów

P_(rms) =(V_(rms) ^2)/R

P_(rms) =I_(rms) ^2 ∙ R

Upraszczając układ równań otrzymujemy

P_(rms) =(P_(max))/2

Co daje nam wynik że moc RMS wynosi około 12,9W

4. Badanie THD

Obraz zawierający linia, tekst, Wykres, diagram Zawartość wygenerowana przez AI może być niepoprawna.

Za pomocą symulacji można było odczytać wartości kolejnych harmonicznych sygnału co pozwala użyć wzoru

THD=(√(U_2^2 +U_3^2 +U_4^2))/(U_1)

Naszą harmoniczną był 1kHz ponieważ taką częstotliwość ustawiliśmy na wejściu układu

Po obliczeniach otrzymaliśmy wynik że

THD = 4,22E-03

5.Badanie Sprawności

Obraz zawierający tekst, linia, Wykres, diagram Zawartość wygenerowana przez AI może być niepoprawna.

Z symulacji wynika że sprawność według wzoru

η=(P_(out RMS))/(I_(spocz) ∙V_(cc))

wynosi 25,32%

Projektu PCB – Wzmacniacz Audio

Cel projektu

Celem projektu było zaprojektowanie i wykonanie wzmacniacza audio o mocy 3 W, z cyfrowym wejściem S/PDIF oraz kontrolą głośności realizowaną za pomocą mikrokontrolera STM32. Główne zadania obejmowały zaprojektowanie schematu ideowego oraz płytki drukowanej (PCB), a następnie przygotowanie symulacji i weryfikacji poprawności działania.

Realizacja projektu

Projekt PCB został wykonany w programie Altium Designer. Główne założenia projektowe obejmowały:

- Odpowiednie szerokości ścieżek sygnałowych i zasilających.
- Uwzględnienie układu elementów ułatwiającego montaż (np. gniazda wejściowe, radiator dla tranzystorów mocy).
- Zapewnienie odpowiednich otworów montażowych.
- Optymalizacja długości ścieżek sygnałowych w krytycznych torach (np. sygnały I2S i sygnały analogowe).
- Podział funkcjonalny – moduły logiczne, analogowe, zasilające i końcówki mocy są rozmieszczone w oddzielnych sekcjach PCB.

Podsumowanie
Projekt PCB został opracowany z uwzględnieniem wymagań wysokiej jakości audio i minimalizacji zakłóceń. Każdy moduł ma przypisane miejsce na płytce, co poprawia czytelność i ułatwia diagnostykę. Końcówka mocy w klasie A oraz wysokiej klasy DAC pozwalają uzyskać sygnał audio HiFi o bardzo niskim poziomie zakłóceń i wysokiej jakości.

Obraz zawierający elektronika, obwód, Inżynieria elektroniczna, Komponent elektroniczny Zawartość wygenerowana przez AI może być niepoprawna.
Obraz zawierający mapa, Jaskrawoniebieski, diagram, tekst Zawartość wygenerowana przez AI może być niepoprawna.
Obraz zawierający tekst, mapa, zrzut ekranu, Prostokąt Zawartość wygenerowana przez AI może być niepoprawna.

Główne komponenty projektu

1. DIR9001 – odbiornik cyfrowego sygnału audio (S/PDIF), konwertujący go na I2S

DIR9001 to odbiornik cyfrowego interfejsu audio, który dekoduje sygnał S/PDIF do standardu I2S. Obsługuje sygnały PCM o częstotliwości próbkowania do 96 kHz i 24-bitowej rozdzielczości. Zapewnia precyzyjne odzyskiwanie zegara i minimalizuje jitter sygnału cyfrowego. Umożliwia łatwe połączenie z przetwornikiem cyfrowo-analogowym.

2. AD1955 – przetwornik C/A wysokiej klasy

Sercem toru audio jest przetwornik cyfrowo-analogowy AD1955. To zaawansowany, 24-bitowy DAC klasy audio o wysokiej jakości dźwięku:

- obsługuje częstotliwości próbkowania do 192 kHz
- zapewnia bardzo niski poziom szumów (SNR do 120 dB) i wysoki współczynnik dynamiki
- umożliwia konwersję sygnału PCM w formacie I2S na sygnał analogowy
- zawiera wbudowaną regulację głośności (tzw. „clickless volume control”) oraz obsługę funkcji mute

AD1955 jest konfigurowany poprzez interfejs SPI, co umożliwia elastyczne sterowanie parametrami pracy.

3. SN74LVU04A – inwertery logiczne dla sygnałów sterujących
4. MJL4281AG – tranzystory bipolarne dużej mocy (NPN), w obudowie TO-3P, zaprojektowane do wzmacniaczy audio klasy AB. Charakteryzują się wysoką liniowością i niskimi zniekształceniami.

Kluczowe parametry MJL4281AG:

- Typ: NPN
- Napięcie kolektor-emiter (Vce): 250 V
- Prąd kolektora (Ic): 15 A (ciągły)
- Moc strat (Ptot): 200 W (przy Tc=25°C)
- β (współczynnik wzmocnienia prądowego): 35–160
- Obudowa: TO-3P (z metalowym wzmocnieniem ułatwiającym odprowadzanie ciepła)
- Pasmo przenoszenia (fT): 30 MHz – umożliwia szerokie pasmo sygnału audio.

Dlaczego MJL4281AG?

- Zapewniają wysoką liniowość – bardzo istotne dla jakości dźwięku w audio HiFi.
- Duża moc wyjściowa – umożliwia bezpieczne oddanie 3 W (z zapasem) przy obciążeniu głośnika 4–8 Ω.
- Wysoka odporność na przeciążenia – minimalizuje ryzyko uszkodzenia końcówki mocy przy wzmacnianiu sygnałów dynamicznych.
- Kompatybilne z klasyczną konfiguracją driverów i stopnia mocy w klasycznych wzmacniaczach audio.
5. BD139 – średniej mocy tranzystory bipolarne NPN w obudowie TO-225, używane do wysterowania tranzystorów mocy.

Parametry BD139:

- Typ: NPN
- Napięcie kolektor-emiter: 80 V
- Prąd kolektora: 1,5 A
- Moc strat: 12,5 W
- Obudowa: TO-225 (plastikowa, łatwa do montażu na radiatorze)
- β (współczynnik wzmocnienia prądowego): 40–250
- Pasmo przenoszenia: 190 MHz – pozwala na szybkie wysterowanie tranzystorów mocy.
6. BC557C – tranzystory PNP małej mocy, stosowane w obwodach polaryzacji lub sprzężenia zwrotnego końcówki mocy.
- Prąd kolektora: 100 mA
- Napięcie kolektor-emiter: 50 V
- β (współczynnik wzmocnienia prądowego): 420–800
- Obudowa: TO-92 (mała, tania)

Wzmacniają sygnały sterujące oraz pełnią funkcje pomocnicze w układach zabezpieczeń lub automatycznego biasowania.

#### 7. Mikrokontroler (STM32F103)

#### Mikrokontroler pełni kluczową rolę w:

- konfiguracji DAC (AD1852 / AD1955) poprzez interfejs SPI
- realizacji cyfrowej regulacji głośności
- ewentualnej komunikacji z użytkownikiem (przyciski, wyświetlacz)

Zapewnia elastyczne sterowanie całym wzmacniaczem i umożliwia łatwą integrację w większym systemie audio.

Bibliografia

- https://chinese-electronics-products-tested.blogspot.com/p/linsley-hood-1969-amplifier-tested.html
- https://sound-au.com/jll_hood.htm
- Dokumentacje zamieszczone w folderze literatura

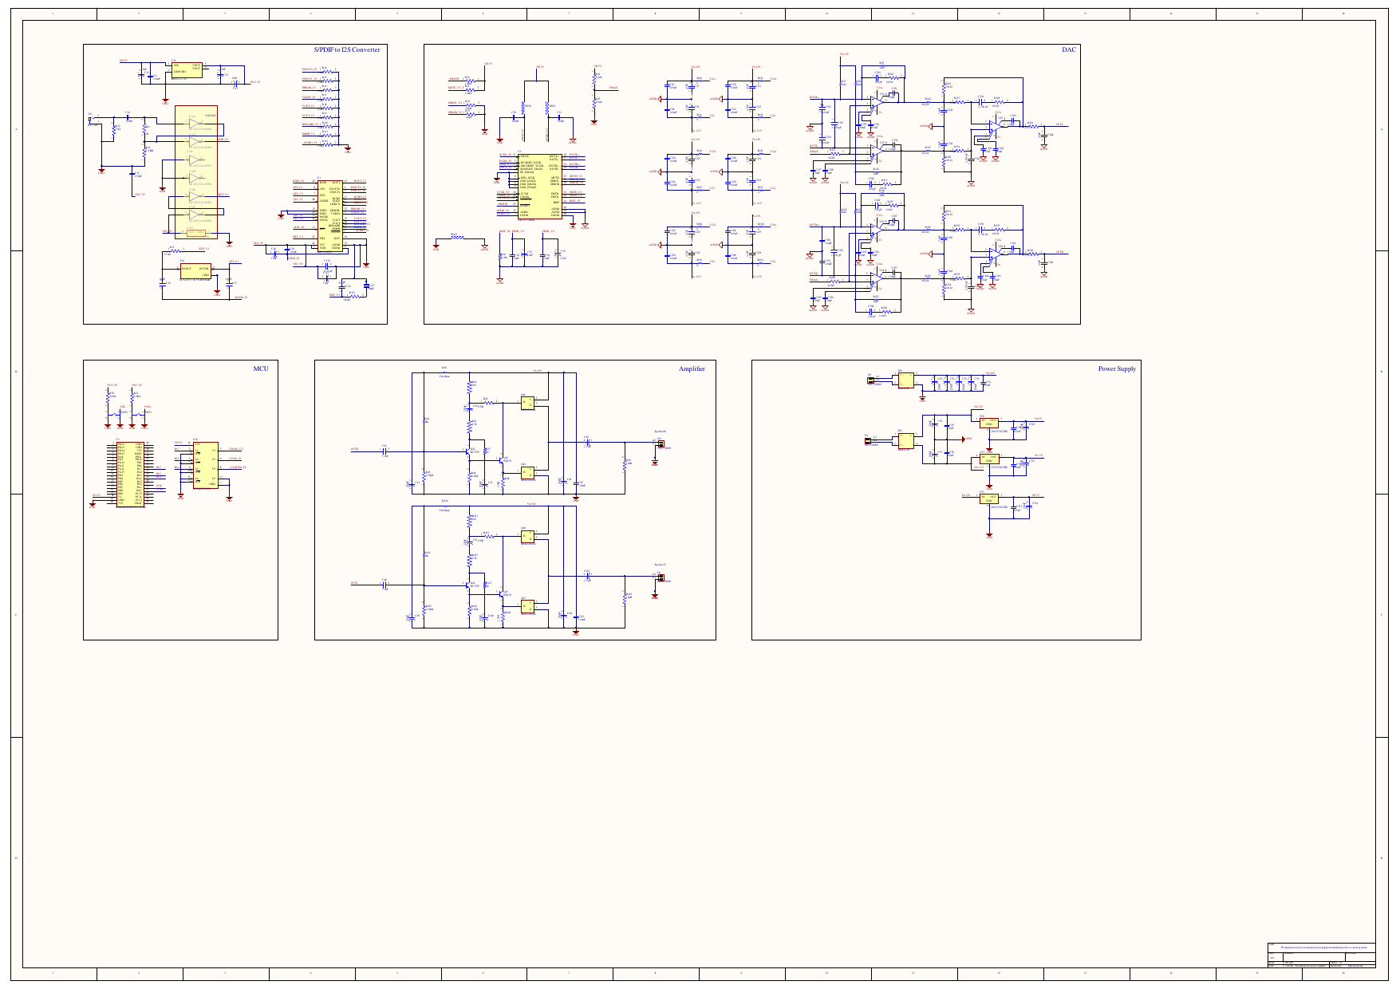
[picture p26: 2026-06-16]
assets/rendered/altium_schemat_overview.png

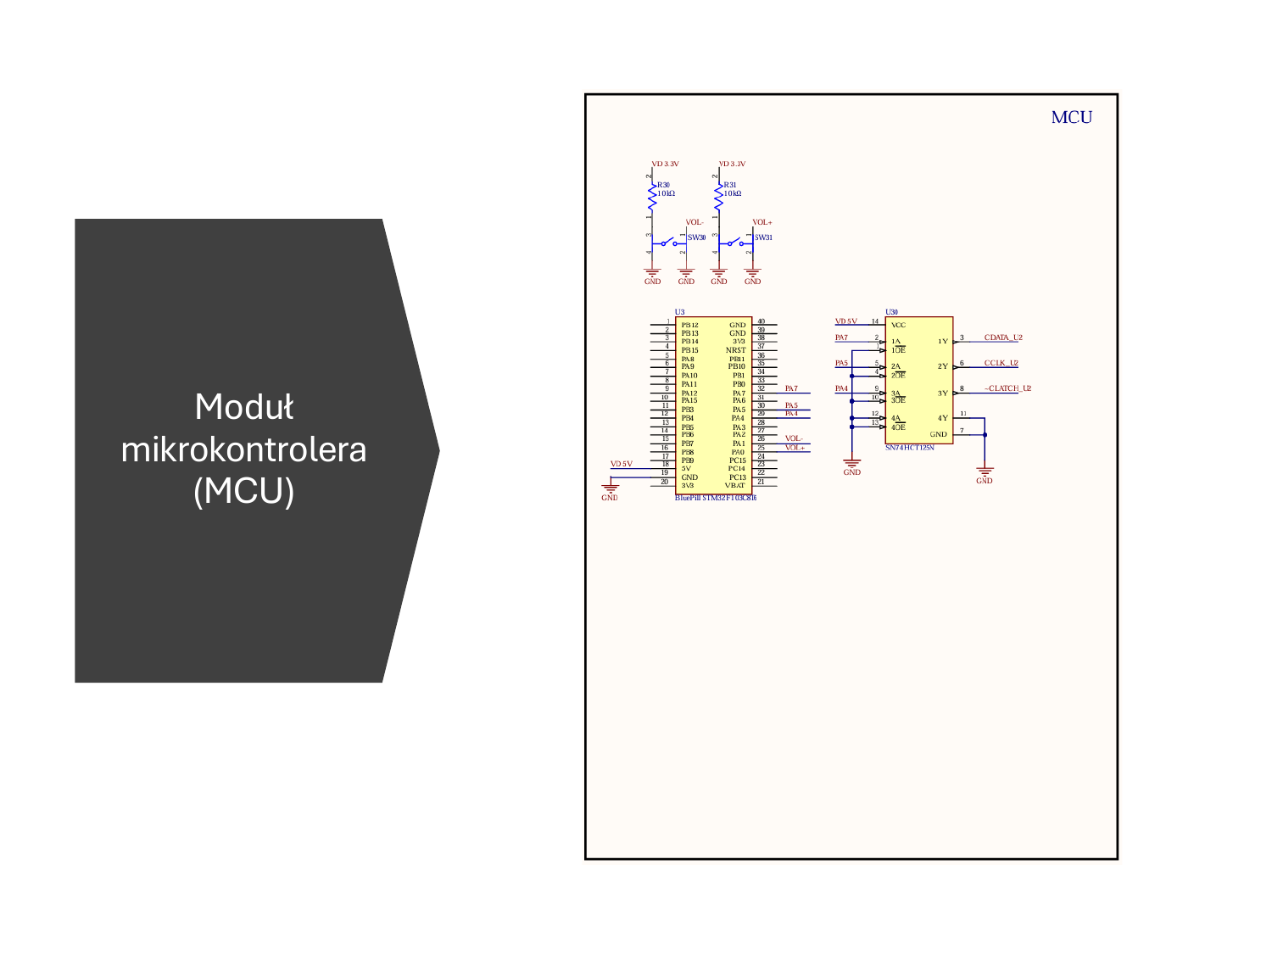
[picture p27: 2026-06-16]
assets/rendered/mcu_schemat.png

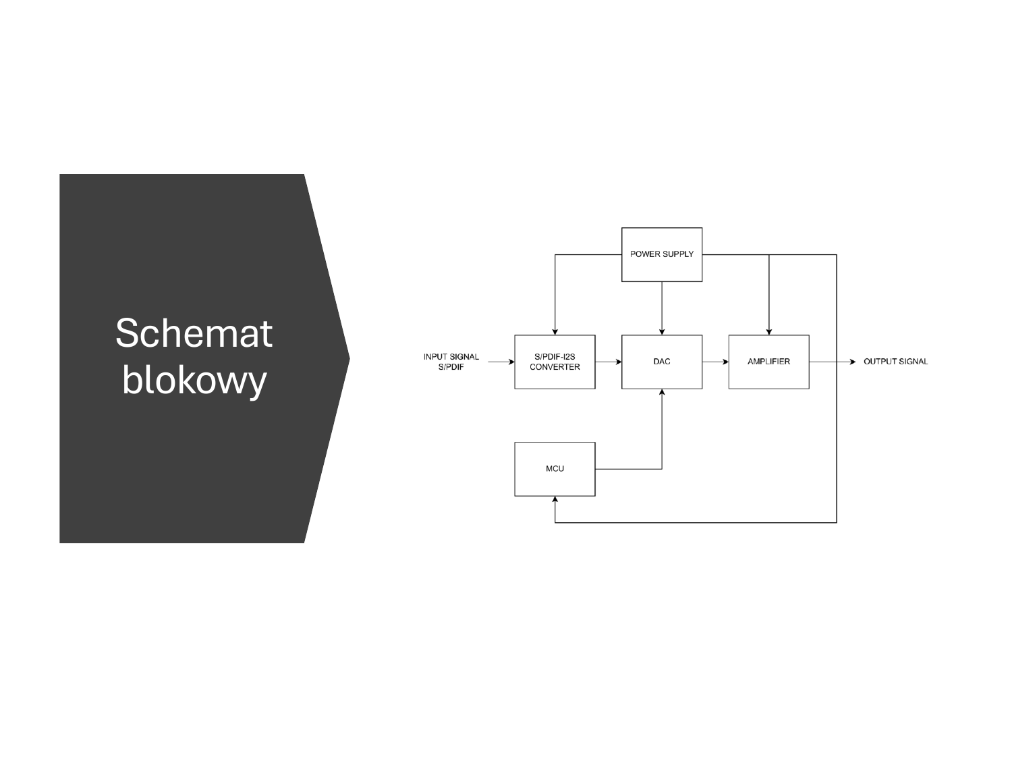
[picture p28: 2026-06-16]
assets/rendered/schemat_blokowy.png

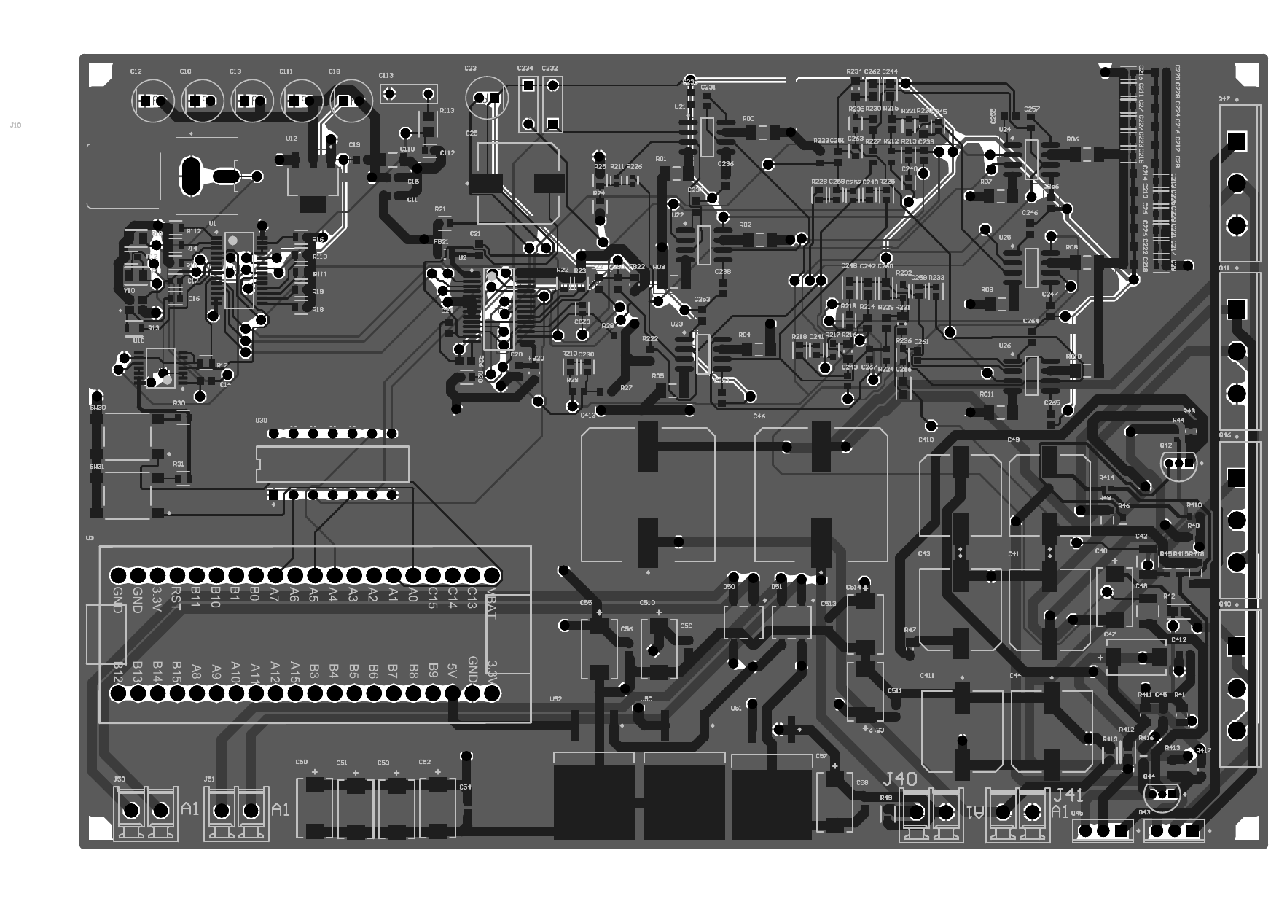
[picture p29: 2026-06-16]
assets/rendered/altium_pcb_layout.png

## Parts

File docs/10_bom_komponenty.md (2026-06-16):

# BOM i komponenty

## Najważniejsze układy

| Element | Funkcja |
|---|---|
| DIR9001 | odbiornik S/PDIF i konwerter do I2S |
| SN74LVU04A | bufor i kształtowanie sygnałów logicznych |
| AD1955 | przetwornik cyfrowo-analogowy audio |
| AD797 | wzmacniacz operacyjny do konwersji I/V |
| STM32F103 | mikrokontroler sterujący DAC |
| MJL4281AG | tranzystor mocy NPN |
| BD139 | tranzystor drivera |
| BC557C | tranzystor pomocniczy PNP |
| REG1117-3.3 | stabilizator 3,3 V |
| L7805 | stabilizator +5 V |
| L7905 | stabilizator -5 V |
| MB6S | mostek prostowniczy |
| RCJ-043 | gniazdo RCA |
| ECS 24,576 MHz | rezonator / kwarc dla toru cyfrowego |

## Rola tranzystorów w końcówce mocy

### MJL4281AG

Tranzystor dużej mocy użyty jako element końcowy wzmacniacza. Daje duży zapas prądowy i napięciowy względem wymaganej mocy wyjściowej.

### BD139

Tranzystor średniej mocy używany jako driver, czyli element sterujący tranzystorem mocy.

### BC557C

Tranzystor PNP małej mocy używany w obwodach polaryzacji, sprzężenia lub funkcjach pomocniczych.

## Uwagi

W repozytorium warto utrzymać katalog `literatura/`, ponieważ zawiera noty katalogowe użytych elementów. Dobrą praktyką jest też dodanie uproszczonego pliku BOM w formacie CSV lub XLSX.

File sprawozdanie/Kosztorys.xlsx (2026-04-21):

Numer na schemacie | Opis elementu | Oznaczenia na PCB | Ilość | Cena jednostkowa [zł] | Cena sumaryczna [zł]
EEUFC1H100LH | Aluminum Electrolytic Capacitors (Radial Lead Type) AEC-Q200 Qualified 10uF ±20% 50V | C10, C12, C13, C18, C23, C111 | 6 | 0.22186 | 1.33116
GRM188R71H104KA93D | Chip Capacitor, 0.1 uF, +/- 10%, 50 V, -55 to 125 degC, 0603 (1608 Metric), RoHS, Tape and Reel | C11, C14, C15, C19, C20, C21, C22, C24, C26, C28, C45, C54, C56, C58, C59, C210, C212, C214, C216, C218, C220, C222, C224, C226, C228, C235, C236, C237, C238, C246, C247, C250, C251, C253, C254, C255, C256, C264, C265, C412, C511, C513 | 42 | 0.08527 | 3.58134
C0603C180J5GACTU | CAP CER 18PF 50V C0G/NP0 0603 | C16, C17 | 2 | 0.36977 | 0.73954
UUX2A470MNL1GS | CAP ALUM 47UF 20% 100V SMD | C25 | 1 | 2.06 | 2.06
CL10A475KP8NNNC | Cap Ceramic 4.7uF 10V X5R ±10% Pad SMD 0603 +85°C T/R | C27, C29, C211, C213, C215, C217, C219, C221, C223, C225, C227, C229 | 12 | 0.02958 | 0.35496
T491D227K016AT | CAP TANT 220UF 10% 16V 2917 | C40, C47, C50, C51, C52, C53, C55, C57, C510, C512, C514 | 11 | 3.66 | 40.26
EEEFK1V331AP | CAP ALUM 330UF 20% 35V SMD | C41, C43, C44, C49, C410, C411 | 6 | 1.15 | 6.9
C3225X7R1H335K250AB | Multilayer Ceramic Capacitors 3.3uF ±10% 50V X7R SMD 1210 | C42, C48 | 2 | 0.7044 | 1.4088
EEV-FK1E222M | EEV-FK1E222M Aluminum Electrolytic Capacitor, Polarized, Aluminum (wet), 35V, 20% +Tol, 20% -Tol, 100uF | C46, C413 | 2 | 2.94 | 5.88
C1206C104G3GACTU | CAP CER 0.1UF 25V NP0 1206 | C110 | 1 | 1.36 | 1.36
C0603C472J5GACTU | CAP CER 4700PF 50V 5% NP0 0603 | C112 | 1 | 0.6 | 0.6
B32529C1683J000 | CAPACITOR POLY FILM 0.068UF, 100V, 5%, RAD; Capacitance:0.068ÂµF; Capacitance Tolerance:Â± 5%; Capacitor Case Style:-; Capacitor Dielectric Type:Polyester (PET); Capacitor Mounting:Through Hole; Capacitor Terminals:Radial Leaded RoHS Compliant: Yes | C113 | 1 | 0.37 | 0.37
C0603C101F5GACTU | CAP CER 100PF 50V 1% NP0 0603 | C230, C233, C240, C249, C252, C258 | 6 | 0.34018 | 2.04108
GRM1885C1H101JA01D |  | C231, C239, C243, C257, C261, C267 | 6 | 0.29581 | 1.77486
B32529C1104J000 | B32529C1104J000 Cap Film 0.1uF 100V PET 5% (7.3 X 2.5 X 6.5mm) Radial Stacked 5mm 125C Automotive Bulk | C232, C234 | 2 | 0.99837 | 1.99674
C0603C272J5GACTU | CAP CER 2700PF 50V C0G/NP0 0603 | C241, C245, C259, C263 | 4 | 0.03624 | 0.14496
GRM1885C1H562JA01D | Chip Multilayer Ceramic Capacitors for General Purpose, 0603, 5600pF, C0G, 30ppm/°C, 5%, 50V | C242, C244, C260, C262 | 4 | 0.44372 | 1.77488
GRM1885C1H392JA01D | Chip Multilayer Ceramic Capacitors for General Purpose, 0603, 3900pF, C0G, 30ppm/°C, 5%, 50V | C248, C266 | 2 | 0.36977 | 0.73954
MB6S-TP | BRIDGE RECT 1P 600V 500MA MBS-1 | D50, D51 | 2 | 1.37 | 2.74
MPZ2012S601A | Chip Bead for Power Line, 600 Ohm, +/- 25%, 2 A, -55 to 125 degC, 2-Pin SMD (0805), RoHS, Tape and Reel | FB20, FB21, FB22 | 3 | 0.095 | 0.285
RCJ-043 | Metal Right-Angle, RCA Jack, White Housing and Insulation | J10 | 1 | 2.96 | 2.96
1863720000 | OMNIMATE Signal - series BC/SC 3.81 | J40, J41, J50, J51 | 4 | 4.14 | 16.56
MJL4281AG | Complementary NPN Silicon Power Bipolar Transistor, 3-Pin TO-3BPL, Pb-Free, Tube | Q40, Q41, Q46, Q47 | 4 | 12.61 | 50.44
BC557C | Amplifier Transistor, PNP Silicon, 3-Pin TO-92, Bulk Box | Q42, Q44 | 2 | 0.1055 | 0.211
BD139 | Plastic Medium-Power Silicon NPN Transistor, 3-Pin TO-225, Bulk Box | Q43, Q45 | 2 | 0.62 | 1.24
RN73R2ATTD75R0F25 | 75Ω ±1% 0.125W, 1/8W Chip Resistor 0805 (2012 Metric) Moisture Resistant Thin Film | R10 | 1 | 0.73953 | 0.73953
RN73R2ATTD47R0B25 | 47Ω ±0.1% 0.125W, 1/8W Chip Resistor 0805 (2012 Metric) Moisture Resistant Thin Film | R11 | 1 | 0.81348 | 0.81348
RT0603FRE072K2L | RES SMD 2.2K OHM 1% 1/10W 0603 | R12 | 1 | 0.25958 | 0.25958
RN73R2ATTD4700B25 | 470Ω ±0.1% 0.125W, 1/8W Chip Resistor 0805 (2012 Metric) Moisture Resistant Thin Film | R13 | 1 | 0.36977 | 0.36977
CRCW060310K0FKEAHP | RES SMD 10K OHM 1% 1/3W 0603 | R14, R15, R16, R17, R18, R19, R20, R21, R22, R23, R24, R25, R30, R31, R110, R111, R112 | 17 | 0.25144 | 4.27448
RC0603FR-072K49L | 2.49 kOhms Â±1% 0.1W, 1/10W Chip Resistor 0603 (1608 Metric) Moisture Resistant Thick Film | R26 | 1 | 0.022 | 0.022
RT0603BRD072KL |  | R27, R28, R29, R212, R222, R223, R224, R227 | 8 | 0.30506 | 2.44048
RC0603FR-0739KL | Chip Resistor, 39 KOhm, +/- 1%, 0.1 W, -55 to 155 degC, 0603 (1608 Metric), RoHS, Tape and Reel | R40, R410 | 2 | 0.0074 | 0.0148
ERJ-P6WF2200V | 220 Ohms Â±1% 0.5W, 1/2W Chip Resistor 0805 (2012 Metric) Automotive AEC-Q200, Pulse Withstanding Thick Film | R41, R411 | 2 | 0.434 | 0.868
ERA-3AEB471V | RES SMD 470 OHM 0.1% 1/10W 0603 | R42, R412 | 2 | 0.36977 | 0.73954
ERJ-P6WF2701V | 2.7 kOhms Â±1% 0.5W, 1/2W Chip Resistor 0805 (2012 Metric) Automotive AEC-Q200, Pulse Withstanding Thick Film | R43, R413 | 2 | 0.417 | 0.834
CRCW040268K0FKED |  | R44, R414 | 2 | 0.05177 | 0.10354
ERA-3AEB104V |  | R45, R415 | 2 | 0.36977 | 0.73954
RC0603FR-078K2L |  | R46, R416 | 2 | 0.0037 | 0.0074
ERJP03F80R6V | RES, THICK FILM, 80R6, 1%, 0.2W, 0603 | R47, R417 | 2 | 0.116 | 0.232
CRCW12061K50FKEA | RES Thick Film, 1.5kΩ, 1%, 0.25W, 100ppm/°C, 1206 | R48, R418 | 2 | 0.40674 | 0.81348
ERA-3AEB103V | RES SMD 10K OHM 0.1% 1/10W 0603 | R49, R419 | 2 | 0.36977 | 0.73954
RN73R2ATTD6800B25 | 680Ω ±0.1% 0.125W, 1/8W Chip Resistor 0805 (2012 Metric) Moisture Resistant Thin Film | R113 | 1 | 1.29 | 1.29
RG1608P-101-B-T5 | Automotive Metal Thin Film Chip Resistor, 0603, 100Ω, 0.1%, 25ppm/°C, 0.1W, 100V | R210, R213, R218, R225, R228, R233 | 6 | 0.25514 | 1.53084
RT0402BRD07402RL | RES 402 OHM 1/16W .1% SMD 0402 | R211, R226 | 2 | 0.6286 | 1.2572
ERA3AEB6810V |  | R214, R215, R229, R230 | 4 | 0.36977 | 1.47908
RG1608P-2260-B-T5 | Automotive Metal Thin Film Chip Resistor, 0603, 226Ω, 0.1%, 25ppm/°C, 0.1W, 100V | R216, R220, R231, R234 | 4 | 0.81348 | 3.25392
RT0603BRD07324RL | RES SMD 324 OHM 0.1% 1/10W 0603 | R217, R221, R232, R235 | 4 | 0.51767 | 2.07068
RT0603BRD07332RL | RES SMD 332 OHM 0.1% 1/10W 0603 | R219, R236 | 2 | 0.51767 | 1.03534
Resistor 0R +/- 5% 1206 250 mW | Chip Resistor, 0 Ohm, +/- 5%, 0.25 W, -55 to 155 degC, 1206 (3216 Metric) | RO0, RO1, RO2, RO3, RO4, RO5, RO6, RO7, RO8, RO9, RO10, RO11 | 12 | 0.05916 | 0.70992
PTS645SM43SMTR92LFS | SWITCH TACTILE SPST-NO 0.05A 12V | SW30, SW31 | 2 | 0.51663 | 1.03326
DIR9001PW | 96 kHz Digital Audio Receiver, 50 ps Jitter, 3.3V, -40 to 85 degC, 28-Pin TSSOP (PW), Green (RoHS & no Sb/Br) | U1 | 1 | 16.9 | 16.9
AD1955ARSZ | High Performance Multibit Sigma-Delta DAC with SACD Playback, 5 V Power Supply, -40 to 85 degC, 28-Pin SSOP (RS-28), RoHS, Tube | U2 | 1 | 81.64 | 81.64
BluePill | Designed By @Alixahedi | U3 | 1 | 20.22 | 20.22
SN74LVU04APWR | Hex Inverters, PW0014A, LARGE T&R | U10 | 1 | 0.96139 | 0.96139
REG1117-3.3 | 800-mA, 15-V, linear voltage regulator | U12 | 1 | 5.42 | 5.42
AD797ARZ | Single Channel Low Noise Operational Amplifier, 8 MHz BW, 20 V/us SR, Industrial, 8-pin SOIC (R-8), Tube | U21, U22, U23, U24, U25, U26 | 6 | 64.01 | 384.06
SN74HCT125N | IC BUF NON-INVERT 5.5V 14DIP | U30 | 1 | 2.33 | 2.33
L7805CD2T-TR | Positive Voltage Regulator, 3-Pin D2PAK, Tape and Reel | U50, U52 | 2 | 1.48 | 2.96
L7905CD2T-TR | Negative Voltage Regulator, -5V, 3-Pin D2PAK, Tape and Reel | U51 | 1 | 3.55 | 3.55
ECS-245.7-8-36-RWN-TR | 24.576 MHz Â±15ppm Crystal 8pF 60 Ohms 4-SMD, No Lead | Y10 | 1 | 1.69 | 1.69
Płytka PCB |  |  |  | 179.58 | 179.58
 |  |  |  | Suma | 874.73665

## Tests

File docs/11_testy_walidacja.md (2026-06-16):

# Testy i walidacja

## Testy przed uruchomieniem

- sprawdzenie poprawności PCB z dokumentacją,
- kontrola zwarć na liniach zasilania,
- sprawdzenie polaryzacji kondensatorów,
- weryfikacja połączeń masy,
- sprawdzenie footprintów elementów aktywnych,
- kontrola zgodności Gerberów z projektem.

## Testy zasilania

- uruchomienie zasilania bez układów wrażliwych,
- pomiar napięcia +36 V,
- pomiar napięć +/-12 V,
- pomiar napięć +/-5 V i +3,3 V,
- sprawdzenie tętnień,
- kontrola temperatury stabilizatorów.

## Testy toru cyfrowego

- sprawdzenie zegara 24,576 MHz,
- sprawdzenie sygnału S/PDIF na wejściu,
- sprawdzenie wyjść I2S z DIR9001,
- sprawdzenie sygnałów po buforze SN74LVU04A.

## Testy DAC

- sprawdzenie komunikacji SPI,
- konfiguracja AD1955,
- test mute,
- test regulacji głośności,
- pomiar sygnału na wyjściu I/V.

## Testy końcówki mocy

- ustawienie punktu pracy,
- pomiar prądu spoczynkowego,
- test bez obciążenia,
- test z obciążeniem 8 ohm,
- pomiar mocy,
- pomiar temperatury tranzystorów,
- pomiar THD, jeśli dostępny jest analizator audio.

## Testy końcowe

- odsłuch kontrolny,
- test pracy przez dłuższy czas,
- kontrola temperatury,
- sprawdzenie stabilności przy różnych poziomach sygnału.

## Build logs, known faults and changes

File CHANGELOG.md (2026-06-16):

# Changelog

## 2026-06-16

### Dodano

- pełny polski README,
- dokumentację techniczną w katalogu `docs/`,
- opis architektury systemu,
- opis toru S/PDIF -> I2S,
- opis DAC AD1955 i toru analogowego,
- opis końcówki mocy klasy A,
- opis zasilania,
- opis sterowania mikrokontrolerem,
- opis symulacji LTspice z wynikami,
- opis PCB w Altium Designer,
- opis komponentów i ich roli,
- checklistę testów,
- opis projektu do CV i portfolio,
- grafiki poglądowe w `assets/rendered/`.

## Poprawka grafik

- Usunięto grafiki pochodzące ze slajdów prezentacji.
- Podmieniono grafiki w `assets/rendered/` na obrazy wyciągnięte z `sprawozdanie/Sprawozdanie.pdf`.
- Zaktualizowano odwołania w README i dokumentacji PCB.

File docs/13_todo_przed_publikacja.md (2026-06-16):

# TODO przed publikacją repozytorium

## Najważniejsze poprawki

- dodać aktualny screenshot schematu z Altium,
- dodać aktualny screenshot PCB top/bottom,
- dodać render 3D PCB,
- dodać screenshoty z LTspice w dobrej jakości,
- dodać uproszczony BOM w CSV,
- opisać, czy powstał fizyczny prototyp,
- dopisać wyniki rzeczywistych pomiarów, jeśli zostały wykonane,
- usunąć pliki tymczasowe i historię `.svn`, jeśli repo ma być czyste,
- sprawdzić, czy można publikować wszystkie noty katalogowe w katalogu `literatura/`,
- uzupełnić sekcję licencji.

## Rekomendowany układ repo

```text
README.md
docs/
assets/
pcb/
sym/
sprawozdanie/
prezentacja/
literatura/
CHANGELOG.md
.gitignore
```

## Co najbardziej podniesie jakość repo

Największy efekt dają: zdjęcia lub rendery PCB, wyniki symulacji, tabela parametrów i jasny opis roli każdego bloku. Repo powinno pokazywać nie tylko pliki projektu, ale też myślenie projektowe.
